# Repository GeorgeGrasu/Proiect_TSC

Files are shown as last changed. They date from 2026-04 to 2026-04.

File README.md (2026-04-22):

# InkTime ⌚ — Smartwatch Open Source

<p align="center">
  InkTime Smartwatch Render
</p>

**InkTime** este un smartwatch open-source, cu cost redus, construit în jurul **Nordic nRF52840** System-on-Chip, echipat cu un **display e-paper de 1.54"**. Proiectat pentru producție de masă, acest proiect acoperă designul hardware complet, de la schemă până la fișierele necesare fabricației.

---

## 📋 Cuprins
- [Diagrama Bloc](#diagrama-bloc)
- [Bill of Materials (BOM)](#bill-of-materials-bom)
- [Funcționalitatea Hardware](#funcționalitatea-hardware)
- [Maparea Pinilor nRF52840](#maparea-pinilor-nrf52840)
- [Analiza Consumului de Energie](#analiza-consumului-de-energie)
- [Designul PCB](#designul-pcb)
- [Design Mecanic](#design-mecanic)
- [Decizii de Design și Observații](#decizii-de-design-și-observații)
- [Structura Repository-ului](#structura-repository-ului)
- [Licență](#licență)

---

## Diagrama Bloc

<p align="center">
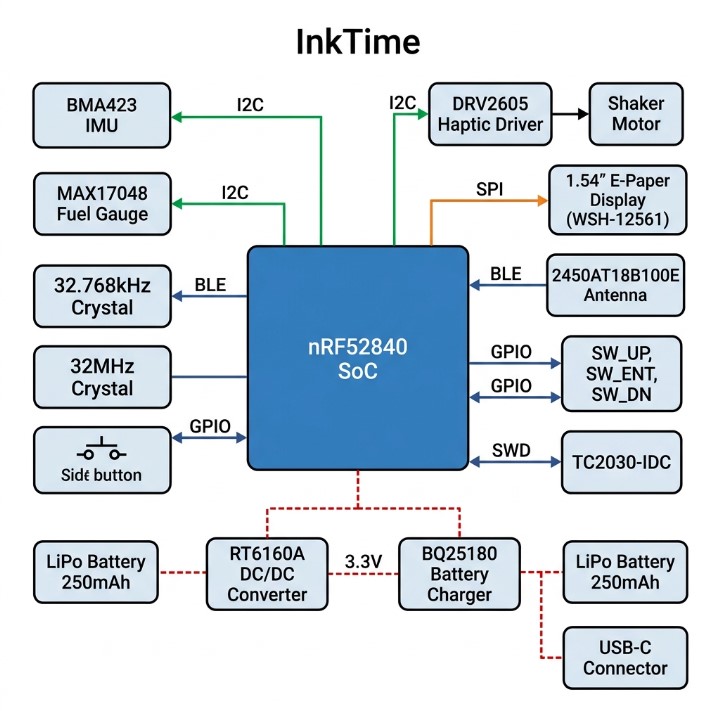
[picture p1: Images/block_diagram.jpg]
InkTime Diagrama Bloc
  
</p>

### Arhitectura Sistemului

```
                            ┌─────────────────────────────────────────────────┐
                            │              nRF52840 SoC (QFN48)              │
                            │                                                 │
                            │  ARM Cortex-M4F @ 64MHz                        │
                            │  1MB Flash / 256KB RAM                          │
                            │  Bluetooth 5.0 / BLE                            │
                            │  USB 2.0 Full Speed                             │
                            │                                                 │
  ┌──────────────┐   SPI    │  P0.02 (SCK)  ──┐                              │
  │  1.54" E-Ink │◄────────►│  P0.03 (MOSI) ──┤ SPI                          │
  │   Display    │          │  P0.28 (MISO) ──┤                              │
  │  (WSH-12561) │          │  P0.29 (CS)   ──┘                              │
  │  200x200 px  │          │  P0.04 (DC)                                     │
  │              │          │  P0.05 (RST)                                    │
  │              │          │  P0.06 (BUSY)                                   │
  └──────────────┘          │                                                 │
                            │                    ┌─────────────────────┐      │
  ┌──────────────┐   I2C    │  P0.26 (SDA) ─────►│ Magistrala I2C      │      │
  │  BMA423 IMU  │◄────────►│  P0.27 (SCL) ─────►│                     │      │
  │ Accelerometru│          │                    │  ├─ BMA423 (0x18)   │      │
  └──────────────┘          │                    │  ├─ MAX17048 (0x36) │      │
                            │                    │  └─ DRV2605 (0x5A)  │      │
  ┌──────────────┐   I2C    │                    └─────────────────────┘      │
  │  MAX17048    │◄─────────│                                                 │
  │ Fuel Gauge   │          │                                                 │
  └──────────────┘          │                                                 │
                            │                                                 │
  ┌──────────────┐   I2C    │                                                 │
  │  DRV2605     │◄─────────│                                                 │
  │ Driver Haptic│          │                                                 │
  │      │       │          │                                                 │
  │  ┌───▼────┐  │          │                                                 │
  │  │ Shaker │  │          │                                                 │
  │  │FIT0774 │  │          │                                                 │
  │  └────────┘  │          │                                                 │
  └──────────────┘          │                                                 │
                            │  P0.13 ──── SW_UP   (Buton)                     │
  ┌──────────────┐   GPIO   │  P0.14 ──── SW_ENT  (Buton)                     │
  │  3 Butoane   │◄────────►│  P0.15 ──── SW_DN   (Buton)                     │
  └──────────────┘          │                                                 │
                            │  P0.18 (D-) ──┐                                 │
  ┌──────────────┐   USB    │  P0.20 (D+) ──┤ USB 2.0 FS                     │
  │   USB-C      │◄────────►│               ──┘                              │
  │  Conector    │          │                                                 │
  │ (KH-TYPE-C)  │          │                                                 │
  └──────────────┘          │  SWDIO ──┐                                      │
                            │  SWDCLK ─┤ SWD Debug                           │
  ┌──────────────┐   SWD    │  SWO ────┘                                      │
  │   TC2030     │◄────────►│                                                 │
  │ Header Debug │          │                                                 │
  └──────────────┘          │  XC1/XC2 ─── Cristal 32 MHz                     │
                            │  P0.00/P0.01 ─── Cristal 32.768 kHz             │
  ┌──────────────┐          │                                                 │
  │  2450AT18B   │◄─────────│  ANT ──── Ieșire RF (2.4 GHz BLE)              │
  │ Antenă Chip  │          │                                                 │
  └──────────────┘          └─────────────────────────────────────────────────┘

  ┌─────────────────────────────────────────────────────────────────┐
  │                  SUBSISTEMUL DE ALIMENTARE                       │
  │                                                                 │
  │  ┌────────┐    ┌───────────┐    ┌───────────┐    ┌───────────┐ │
  │  │ USB-C  │───►│ BQ25180   │───►│ Baterie   │    │ RT6160A   │ │
  │  │  5V    │    │ Încărcător│    │ LiPo      │───►│ DC/DC     │ │
  │  │        │    │           │    │ 250mAh    │    │ Buck      │ │
  │  └────────┘    └───────────┘    │ 3.7V      │    │ 3.3V Ieș  │ │
  │                                 └───────────┘    └─────┬─────┘ │
  │  ┌────────────┐                                         │       │
  │  │ DMG2305UX  │◄── Comutator Sarcină (PMOS) ────────────┘       │
  │  │ P-MOSFET   │                                                 │
  │  └────────────┘         Linie 3.3V ──► Toate IC-urile           │
  └─────────────────────────────────────────────────────────────────┘
```

---

## Bill of Materials (BOM)

### Circuite Integrate și Module Principale

| # | Referință | Componentă | Valoare / Cod | Capsulă | Cant. | JLC Parts | Datasheet |
|---|---|---|---|---|-----|---|---|
| 1 | U1 | Microcontroler | nRF52840-QIAA | aQFN73 (7x7mm) | 1 | [C190794](https://jlcpcb.com/parts/componentSearch?isSearch=true&searchTxt=nRF52840) | [Datasheet](https://infocenter.nordicsemi.com/pdf/nRF52840_PS_v1.8.pdf) |
| 2 | IC2 | Încărcător Baterie | BQ25180YBGR | DSBGA-8 | 1 | [C2682092](https://jlcpcb.com/parts/componentSearch?isSearch=true&searchTxt=BQ25180) | [Datasheet](https://www.ti.com/lit/ds/symlink/bq25180.pdf) |
| 3 | IC9 | Convertor DC/DC | RT6160AWSC | WLCSP-15 | 1 | [C2828036](https://jlcpcb.com/parts/componentSearch?isSearch=true&searchTxt=RT6160A) | [Datasheet](https://www.richtek.com/assets/product_file/RT6160A/DS6160A-05.pdf) |
| 4 | U3 | Indicator Baterie | MAX17048G+T10 | DFN 2x2-8 | 1 | [C2682766](https://jlcpcb.com/parts/componentSearch?isSearch=true&searchTxt=MAX17048) | [Datasheet](https://datasheets.maximintegrated.com/en/ds/MAX17048-MAX17049.pdf) |
| 5 | IC3 | IMU / Accelerometru | BMA423 | LGA-12 | 1 | [C2831316](https://jlcpcb.com/parts/componentSearch?isSearch=true&searchTxt=BMA423) | [Datasheet](https://www.bosch-sensortec.com/products/motion-sensors/accelerometers/bma423/) |
| 6 | IC1 | Driver Haptic | DRV2605YZFR | BGA-9 | 1 | [C527680](https://jlcpcb.com/parts/componentSearch?isSearch=true&searchTxt=DRV2605) | [Datasheet](https://www.ti.com/lit/ds/symlink/drv2605.pdf) |
| 7 | D1 | Protecție ESD USB | USBLC6-2SC6Y | SOT-23-6 | 1 | [C7519](https://jlcpcb.com/parts/componentSearch?isSearch=true&searchTxt=USBLC6-2SC6Y) | [Datasheet](https://www.st.com/resource/en/datasheet/usblc6-2.pdf) |
| 8 | DMG2305UX | Comutator PMOS | DMG2305UX-7 | SOT-23-3 | 1 | [C150812](https://jlcpcb.com/parts/componentSearch?isSearch=true&searchTxt=DMG2305UX) | [Datasheet](https://www.diodes.com/assets/Datasheets/DMG2305UX.pdf) |
| 9 | Q3 | MOSFET (Driver motor) | SI1308EDL-T1-GE3 | SC-70-3 | 1 | [C515086](https://jlcpcb.com/parts/componentSearch?isSearch=true&searchTxt=SI1308EDL) | [Datasheet](https://www.vishay.com/docs/68743/si1308edl.pdf) |

### Conectori

| # | Referință | Componentă | Cod Componentă | Capsulă | Cant. | JLC Parts |
|---|---|---|---|---|-----|---|
| 10 | J1 | Conector FPC pentru EPD | 503480-2400 (24-pin, 0.5mm) | SMD | 1 | [C585393](https://jlcpcb.com/parts/componentSearch?isSearch=true&searchTxt=503480-2400) |
| 11 | J2 | Header de Debug | TC2030-IDC | Through-hole | 1 | [C5191042](https://jlcpcb.com/parts/componentSearch?isSearch=true&searchTxt=TC2030) |
| 12 | J4 | Conector USB-C | KH-TYPE-C-16P | SMD | 1 | [C2765186](https://jlcpcb.com/parts/componentSearch?isSearch=true&searchTxt=KH-TYPE-C-16P) |

### Componente Pasive

| # | Referință | Componentă | Valoare | Capsulă | Cant. |
|---|---|---|---|---|-----|
| 13 | C1, C2, C17, C18 | Condensator | 12pF | 0201 | 4 |
| 14 | C3, C4 | Condensator | 1pF | 0201 | 2 |
| 15 | C5, C7, C8, C12, C19 | Condensator | 100nF | 0201 | 5 |
| 16 | C6, C14, C20, C21 | Condensator | 4.7µF | 0402 | 4 |
| 17 | C9 | Condensator | 820pF | 0201 | 1 |
| 18 | C11 | Condensator | 100pF | 0201 | 1 |
| 19 | C16 | Condensator | 27nF | 0201 | 1 |
| 20 | C1-EP-DR | Condensator | 10µF | 0402 | 1 |
| 21 | C2-EP-DR | Condensator | 4.7µF/25V | 0402 | 1 |
| 22 | C23, C34 | Condensator | 0.1µF | 0201 | 2 |
| 23 | C24 | Condensator | 10µF | 0402 | 1 |
| 24 | C25, C33 | Condensator | 22µF | 0402 | 2 |
| 25 | C32 | Condensator | 1µF | 0402 | 1 |
| 26 | C43 | Condensator | 4.7µF | 0402 | 1 |
| 27 | C27, C29, C30, C31, C42 | Condensator | GRM011R60J152KE01 (1.5nF) | 0201 | 5 |
| 28 | EPD_C1, EPD_C2 | Condensator | 1µF/50V | 0402 | 2 |
| 29 | EPD_C5–C12 | Condensator | 0.1µF/50V | 0201 | 8 |
| 30 | L1 | Bobină | 3.9nH | 0402 | 1 |
| 31 | L2 | Bobină | 10µH | 0402 | 1 |
| 32 | L3 | Bobină | 15nH | 0402 | 1 |
| 33 | L5 | Bobină | 68µH | 4828 | 1 |
| 34 | L7 | Bobină | 0.47µH | 2016 | 1 |
| 35 | R17, R18, R1_EP_DR–R9, R_PWR_EPD, R_TYPE_SEL | Rezistoare | Diverse | 0402 | 14 |
| 36 | D3, D4, D5 | Diodă Schottky | MBR0530 | SOD-323 | 3 |
| 37 | ANT1 | Antenă Chip | 2450AT18B100E | 3216 | 1 |
| 38 | X1 | Cristal | 32 MHz | 2016 | 1 |
| 39 | X2 | Cristal | 32.768 kHz | 3215 | 1 |
| 40 | SW_UP, SW_ENT, SW_DN | Buton Tactil | EVP-AKE31A | SMD | 3 |
| 41 | SJ1 | Jumper de Lipit | – | SMD | 1 |
| 42 | TP_* | Pad-uri de Test | – | TP20R | 14 |

### Componente Externe (nu sunt pe PCB)

| # | Componentă | Cod | Specificații | Link |
|---|---|---|---|---|
| 43 | Baterie LiPo | Akyga AKY0106 (LP502030) | 3.7V, 250mAh, 30×20×5mm | [TME](https://www.tme.eu/Document/b9e12bf26ad0ba929a22ab5d58f022cd/AKY0106.pdf) |
| 44 | Display E-Paper | Waveshare WSH-12561 (1.54") | 200×200px, 31.8×37.32×1.05mm | [TME](https://www.tme.eu/Document/0ca57a8ffbcd57b5bca53252eb9d6ec3/WSH-12561.pdf) |
| 45 | Motor de Vibrație | DFRobot FIT0774 | Ø10×2.7mm, 3V/50mA | [DFRobot](https://www.tme.eu/ro/details/df-fit0774/motoare-dc/dfrobot/fit0774/) |

---

## Funcționalitatea Hardware

### 1. Procesor și Conectivitate — nRF52840 (U1)

**Nordic nRF52840** este SoC-ul principal, oferind:
- **ARM Cortex-M4F** la **64 MHz** cu FPU (unitate de calcul în virgulă mobilă)
- **1 MB Flash** și **256 KB RAM**
- **Bluetooth 5.0 / BLE** prin radio integrat la 2.4 GHz
- **USB 2.0 Full-Speed** pentru transfer de date și negociere de încărcare
- **Convertor DC/DC integrat** pentru management eficient al puterii
- **ARM TrustZone CryptoCell-310** pentru securitate

nRF52840 este în capsulă **QFN73 (7×7mm)** cu matrice de pad-uri de tip BGA, suficient de compact pentru aplicații wearable.

**Surse de ceas:**
- **X1**: Cristal de 32 MHz — ceasul principal de sistem pentru radio și CPU
- **X2**: Cristal de 32.768 kHz — RTC de consum redus și timer de sleep

### 2. Display E-Paper — WSH-12561 (prin J1)

**Display-ul Waveshare e-paper de 1.54"** oferă:
- Rezoluție de **200×200 pixeli**
- **Consum ultra-redus** — consumă energie doar la reîmprospătare (refresh)
- **Interfață SPI** pentru comunicare rapidă
- Conectat prin conector **FPC cu 24 de pini, pas 0.5mm** (J1: Molex 503480-2400)

Circuitul driver EPD al display-ului necesită mai multe tensiuni de alimentare, generate prin pompele de sarcină (charge pumps) cu condensatoarele EPD_C1–C12.

**Semnale de interfață:**
| Semnal | Pin nRF52840 | Descriere |
|---|---|---|
| SCLK | P0.02 | Ceas SPI |
| MOSI | P0.03 | Date SPI spre display |
| MISO | P0.28 | Date SPI de la display |
| CS | P0.29 | Chip Select (activ pe low) |
| DC | P0.04 | Selectare Date/Comandă |
| RST | P0.05 | Reset display (activ pe low) |
| BUSY | P0.06 | Indicator display ocupat |

### 3. Unitate de Măsură Inerțială — BMA423 (IC3)

**Bosch BMA423** este un accelerometru digital pe 3 axe, oferind:
- Numărare pași, recunoaștere activitate, detecție gesturi
- **Interfață I2C** (adresă: 0x18)
- Consum ultra-redus (~14 µA în modul low-power)
- Ideal pentru detecția ridicării încheieturii (wake on raise)

Conectat prin magistrala I2C comună (SDA: P0.26, SCL: P0.27).

### 4. Managementul Bateriei — BQ25180 (IC2) + MAX17048 (U3)

**Încărcător Baterie BQ25180 (IC2):**
- **Încărcător liniar** optimizat pentru dispozitive wearable
- Intrare de la USB-C (VBUS, 5V)
- Curent de încărcare programabil
- Parametri de încărcare **configurabili prin I2C**
- Capsulă compactă **DSBGA-8** (1.0×1.55mm)

**Indicator Baterie MAX17048 (U3):**
- Algoritm **ModelGauge™** — nu necesită rezistor de sens
- Raportează **starea de încărcare (SOC %)** și tensiunea
- **Interfață I2C** (adresă: 0x36)
- Curent de repaus ultra-redus (~23 µA)
- Capsulă **DFN 2×2mm**

**Traseul de alimentare:**
USB-C 5V → BQ25180 → Baterie LiPo (3.7V) → RT6160A → Linie de 3.3V pentru sistem

### 5. Regulare de Tensiune — RT6160A (IC9)

**Richtek RT6160A** este un convertor DC/DC de tip buck:
- Intrare: 2.5V – 5.5V (de la baterie sau USB)
- Ieșire: **3.3V** reglat
- Curent de ieșire de până la **2A**
- **Eficiență de 96%** la sarcină tipică
- Capsulă **WLCSP-15** (1.4×2.3mm)

Linia de 3.3V alimentează toate circuitele integrate, senzorii și display-ul.

**Componente suport:**
- **L7** (0.47µH) — bobina principală de comutare
- **C25, C33** (22µF) — condensatoare de ieșire
- **C23** (0.1µF), **C24** (10µF) — condensatoare de intrare

### 6. Feedback Haptic — DRV2605 (IC1) + FIT0774

**TI DRV2605** — driver pentru feedback haptic:
- Suport integrat pentru motoare **ERM și LRA**
- **Bibliotecă de 123 efecte haptice** (forme de undă)
- **Interfață I2C** (adresă: 0x5A)
- Conectat la motorul de vibrație **DFRobot FIT0774** (Ø10×2.7mm)
- Moduri de intrare PWM și analogic disponibile

### 7. Interfața USB-C — KH-TYPE-C-16P (J4)

- Conector **USB Type-C cu 16 pini**
- Suportă **USB 2.0 Full Speed** (D+/D- prin nRF52840)
- **Protecție ESD** prin USBLC6-2SC6Y (D1)
- **Rezistoarele pull-down CC** (R1_USB, R2_USB) pentru detectarea corectă USB-C
- Furnizează de asemenea **alimentare VBUS** către încărcătorul BQ25180

### 8. Interfața Utilizator — 3 Butoane

Trei butoane tactile **EVP-AKE31A** pentru navigare:
| Buton | Pin nRF52840 | Funcție |
|---|---|---|
| SW_UP | P0.13 | Derulare sus / Anterior |
| SW_ENT | P0.14 | Selectare / Enter |
| SW_DN | P0.15 | Derulare jos / Următor |

Amplasate pe marginea stângă a PCB-ului pentru operare ca butoane laterale. Fiecare buton este conectat cu pull-up intern și utilizează detecție de întrerupere pe front descrescător.

### 9. Interfața de Debug — TC2030-IDC (J2)

**Tag-Connect TC2030-IDC** oferă:
- Interfață **SWD (Serial Wire Debug)**
- Footprint cu **pini pogo fără picioare** (economisește spațiu pe PCB)
- Semnale: SWDIO, SWDCLK, SWO, VCC, GND, RESET

### 10. Antena BLE — 2450AT18B100E (ANT1)

- Antenă chip **Johanson 2450AT18B100E**
- **2.4 GHz** pentru Bluetooth Low Energy
- Footprint **3.2×1.6mm** (capsulă 3216)
- Rețea de adaptare: L1 (3.9nH), C3, C4 (1pF)
- **Amplasare critică**: la marginea plăcii, cu decupaj în planul de masă sub antenă

### 11. Protecție și Comutare de Putere

- **DMG2305UX-7** MOSFET canal P — comutator de sarcină pentru managementul puterii
- **MBR0530** diode Schottky (D3, D4, D5) — protecție la tensiune inversă pe liniile de alimentare
- **SI1308EDL** MOSFET canal N (Q3) — comutare motor/periferice

---

## Maparea Pinilor nRF52840

| Pin | GPIO | Funcție | Interfață | Direcție | Note |
|-----|---|---|---|---|---|
| P0.00 | XL1 | Cristal 32.768 kHz | LFCLK | I/O | Ceas de frecvență joasă |
| P0.01 | XL2 | Cristal 32.768 kHz | LFCLK | I/O | Ceas de frecvență joasă |
| P0.02 | AIN0 | Ceas SPI EPD | SPI SCK | Ieșire | Ceas display e-paper |
| P0.03 | AIN1 | SPI MOSI EPD | SPI MOSI | Ieșire | Date spre display |
| P0.04 | AIN2 | Date/Comandă EPD | GPIO | Ieșire | Selectare D/C |
| P0.05 | AIN3 | Reset EPD | GPIO | Ieșire | Reset activ pe low |
| P0.06 | AIN4 | Busy EPD | GPIO | Intrare | Indicator display ocupat |
| P0.13 | — | Buton SUS | GPIO | Intrare | Pull-up intern, IRQ |
| P0.14 | — | Buton ENTER | GPIO | Intrare | Pull-up intern, IRQ |
| P0.15 | — | Buton JOS | GPIO | Intrare | Pull-up intern, IRQ |
| P0.18 | — | USB D- | USB | I/O | Date USB 2.0 minus |
| P0.20 | — | USB D+ | USB | I/O | Date USB 2.0 plus |
| P0.26 | — | I2C SDA | TWI | I/O | Date I2C partajate |
| P0.27 | — | I2C SCL | TWI | Ieșire | Ceas I2C partajat |
| P0.28 | AIN4 | SPI MISO EPD | SPI MISO | Intrare | Date de la display |
| P0.29 | AIN5 | SPI CS EPD | SPI CS | Ieșire | Selectare chip, activ low |
| SWDIO | — | Date Debug | SWD | I/O | Programare/depanare |
| SWDCLK | — | Ceas Debug | SWD | Intrare | Programare/depanare |
| SWO | — | Trasare Debug | SWD | Ieșire | Ieșire de trasare |
| XC1 | — | Cristal 32 MHz | HFCLK | I/O | Ceas de frecvență înaltă |
| XC2 | — | Cristal 32 MHz | HFCLK | I/O | Ceas de frecvență înaltă |
| ANT | — | Antenă RF | Radio | Ieșire | Antenă BLE 2.4 GHz |
| VDD | — | Alimentare | PWR | Intrare | 3.3V de la RT6160A |
| VSS | — | Masă | PWR | — | Planul de masă |
| DEC1–DEC6 | — | Decuplare | PWR | — | Condensatoare 100nF necesare |

**Motivarea alegerii pinilor:**
- **P0.02–P0.06** au fost aleși pentru display-ul SPI deoarece suportă perifericul SPIM la viteză mare și sunt adiacenți pentru rutare curată
- **P0.13–P0.15** pentru butoane deoarece aceste GPIO-uri suportă GPIOTE (evenimente/întreruperi) și nu au conflicte cu funcții alternative
- **P0.26–P0.27** pentru I2C deoarece aceștia sunt pinii impliciți TWI0 ai nRF52840
- **P0.18, P0.20** sunt pinii dedicați USB D-/D+ (nu există alternativă)
- **P0.28–P0.29** pentru semnale SPI suplimentare, utilizând pinii AIN care sunt liberi deoarece nu folosim ADC-ul în acest design

---

## Analiza Consumului de Energie

### Bugetul de Putere per Componentă

| Componentă | Curent Activ | Curent Sleep/Idle | Ciclu de Lucru | Curent Mediu |
|---|---|---|---|---|
| nRF52840 (CPU activ) | 3.2 mA | 1.5 µA (System OFF) | 5% | 161.5 µA |
| nRF52840 (BLE TX) | 4.8 mA | — | 1% | 48 µA |
| Display E-Paper | 15 mA (refresh) | 0 µA (static) | 0.5% | 75 µA |
| BMA423 IMU | 150 µA | 14 µA (low-power) | 10% | 27.6 µA |
| MAX17048 Fuel Gauge | 23 µA | 23 µA (mereu activ) | 100% | 23 µA |
| DRV2605 + Motor | 50 mA | 0.25 µA (standby) | 0.1% | 50.3 µA |
| RT6160A Quiescent | — | 25 µA | 100% | 25 µA |
| **TOTAL** | — | — | — | **~410 µA** |

### Estimarea Autonomiei Bateriei

| Parametru | Valoare |
|---|---|
| Capacitate baterie | 250 mAh |
| Curent mediu de sistem | ~410 µA |
| **Autonomie estimată** | **~610 ore (~25 zile)** |
| Cu optimizare agresivă de sleep | **~40+ zile** |

> **Notă:** Display-ul e-paper are consum zero de energie atunci când afișează o imagine statică, ceea ce este ideal pentru o aplicație de ceas. Display-ul consumă energie doar în timpul reîmprospătării (~2 secunde per actualizare). Advertising-ul BLE la intervale de 1 secundă adaugă ~48 µA în medie.

---

## Designul PCB

### Specificații Placă

| Parametru | Valoare |
|---|---|
| Straturi | 2 (Top + Bottom) |
| Material | FR-4 |
| Grosime | 1.6 mm |
| Greutate cupru | 1 oz (35 µm) |
| Finisaj suprafață | HASL/ENIG |
| Lățime minimă traseu | 0.15 mm (semnale), 0.3 mm (putere) |
| Dimensiune minimă via | 0.3 mm gaură / 0.6 mm pad |
| Față cu componente | Doar TOP |

### Reguli de Design Aplicate

- ✅ **Trasee de putere**: lățime 0.3 mm (mai înguste sub BGA unde este necesar)
- ✅ **Trasee de semnal**: ≥0.15 mm lățime
- ✅ **Fără unghiuri drepte** în rutarea traseelor (45° sau curbate)
- ✅ **Condensatoare de decuplare** (100nF) plasate cât mai aproape de pinii de alimentare ai IC-urilor
- ✅ **Planuri de masă** atât pe TOP cât și pe BOTTOM
- ✅ **Via stitching** între planurile de masă (în special lângă secțiunea RF)
- ✅ **Zona antenei**: planul de masă eliminat sub antenă, fără rutare de semnale pe sub antenă
- ✅ **DRC verificat** folosind regulile de design JLCPCB 2 straturi
- ✅ **Componente plasate exclusiv pe layer-ul TOP**
- ✅ **Pad-urile de test clar marcate** în silkscreen cu numele semnalelor

### Randări PCB

<p align="center">
  PCB Vedere 3D
  <br><em>PCB — Randare 3D</em>
</p>

---

## Design Mecanic

### Dimensiuni Componente

| Componentă | Lungime (mm) | Lățime (mm) | Înălțime (mm) | Sursă |
|---|---|---|---|---|
| Baterie (AKY0106) | 30.0 | 20.0 | 5.0 | [Datasheet](https://www.tme.eu/Document/b9e12bf26ad0ba929a22ab5d58f022cd/AKY0106.pdf) |
| Display (WSH-12561) | 37.32 | 31.80 | 1.05 | [Datasheet](https://www.tme.eu/Document/0ca57a8ffbcd57b5bca53252eb9d6ec3/WSH-12561.pdf) |
| Shaker (FIT0774) | Ø10.0 | Ø10.0 | 2.7 | [DFRobot](https://www.dfrobot.com/product-2288.html) |
| PCB | ~40 | ~36 | 1.6 | Design propriu |
| Carcasă (exterior) | ~42 | ~38 | ~12 | inktime_case.f3z |

### Stack-up Asamblare (de jos în sus)

```
┌─────────────────────────┐
│   Capac Carcasă / Sticlă │  ~1.7 mm
├─────────────────────────┤
│    Display E-Paper       │  1.05 mm
├─────────────────────────┤
│    PCB (cu IC-uri)       │  1.6 mm + ~1 mm (componente)
├─────────────────────────┤
│  Baterie + Shaker        │  5.0 mm (baterie) / 2.7 mm (shaker)
├─────────────────────────┤
│   Baza Carcasei          │  ~1.0 mm perete
└─────────────────────────┘
```

### Modele 3D

Modele parametrice OpenSCAD sunt furnizate în folderul `Mechanical/`:
- `battery_AKY0106.scad` — Model baterie cu dimensiuni exacte
- `display_WSH12561.scad` — Display e-paper cu cablu FPC
- `shaker_FIT0774.scad` — Motor de vibrație tip monedă
- `full_assembly.scad` — Ansamblu complet cu opțiune de vedere explodată

> **Pentru export ca STEP:** Deschideți în OpenSCAD → Exportați ca STL → Importați în FreeCAD/Fusion 360 → Exportați ca STEP

### Vedere Explodată

<p align="center">
  Vedere Explodată Ansamblu
  <br><em>Vedere explodată a ansamblului smartwatch-ului InkTime</em>
</p>

<p align="center">
  Smartwatch fără ecran
  <br><em>Smartwatch-ul InkTime fără ecran (vedere interioară)</em>
</p>

---

## Decizii de Design și Observații

### Decizii Cheie de Design

1. **Conectarea bateriei prin pad-uri de test (fără conector JST)**
   - Decizie: Firele bateriei sunt lipite direct pe pad-urile de test TP_BAT și TP_BAT_GND
   - Motiv: Economisire de spațiu pe înălțime (Z) în interiorul carcasei; conectorul JST ar adăuga ~3mm înălțime

2. **PCB cu 2 straturi**
   - Planuri de masă atât pe TOP cât și pe BOTTOM
   - Via stitching folosit extensiv lângă secțiunea RF/antenă pentru continuitatea masei
   - Majoritatea rutării pe layer-ul TOP; BOTTOM folosit pentru masa și câteva trasee de semnal

3. **Toate componentele pe layer-ul TOP**
   - Conform cerințelor proiectului, toate componentele SMD sunt plasate exclusiv pe TOP
   - Aceasta simplifică asamblarea (reflow pe o singură față) și reduce costul

4. **Componente pasive**
   - Toate rezistoarele sunt SMD 0402
   - Condensatoarele ≤100nF sunt 0201, >100nF sunt 0402
   - Excepție: valori mai mari (22µF) și capsule specifice notate în schemă

5. **Amplasarea antenei**
   - Antena chip (2450AT18B100E) plasată la marginea plăcii
   - Cuprul de masă al PCB-ului eliminat sub footprint-ul antenei
   - Fără rutare de semnale sub sau în apropierea zonei antenei
   - Rețea de adaptare (L1=3.9nH, C3/C4=1pF) acordată conform designului de referință Nordic

### Note ERC/DRC Acceptate

- ⚠️ **"Only INPUT pins on NET ID"** — Această eroare ERC este așteptată și poate fi ignorată în siguranță conform ghidului proiectului
- ⚠️ **Erori de dimensiune de la butoane/USB** — Cele trei butoane tactile și conectorul USB-C se extind ușor dincolo de conturul PCB-ului pentru acces mecanic din carcasă. Aceste încălcări de dimensiune sunt intenționate și acceptate
- ⚠️ **Variația lățimii traseelor sub BGA** — Sub capsula QFN a nRF52840, lățimile traseelor sunt reduse pentru a încăpea între pad-uri. Traseele de putere revin la lățimea de 0.3mm după ieșirea din zona BGA

### Jurnal de Design

| Săptămâna | Activitate |
|---|---|
| Săpt. 1 | Studiu documente InkTime MRD/PRD/ERD, analiză design de referință nRF52840 |
| Săpt. 2 | Implementare schemă în Fusion 360 Electronics folosind biblioteca furnizată |
| Săpt. 3 | Layout PCB — amplasare componente respectând constrângerile mecanice |
| Săpt. 4 | Rutare trasee, verificare DRC, planuri de masă, via stitching |
| Săpt. 5 | Generare Gerber, export BOM/PnP, modelare 3D, documentație |

---

## Structura Repository-ului

```
proiect_TSC/
├── Hardware/
│   ├── SchematicBomba.sch          # Fișier schemă Fusion 360
│   └── PCB.brd                     # Fișier layout placă Fusion 360
├── Manufacturing/
│   ├── GerberFiles.zip             # Fișiere Gerber pentru fabricația PCB
│   ├── Assembly/
│   │   ├── PCB.txt                 # Bill of Materials (BOM)
│   │   └── PnP_PCB_front.txt      # Fișier Pick and Place (CPL)
│   └── DrillFiles/
│       └── drill_1_64.xln          # Fișier de găurire Excellon
├── Mechanical/
│   ├── battery_AKY0106.scad        # Model 3D — Baterie LiPo (30×20×5mm)
│   ├── display_WSH12561.scad       # Model 3D — Display e-paper 1.54"
│   ├── shaker_FIT0774.scad         # Model 3D — Motor vibrație (Ø10×2.7mm)
│   └── full_assembly.scad          # Ansamblu complet cu vedere explodată
├── Images/
│   ├── 3dpcb.jpg                   # Randare PCB 3D
│   ├── block_diagram.jpg           # Diagrama bloc a sistemului
│   ├── inktime-3d-expanded-view.jpg# Vedere explodată ansamblu
│   ├── inktime-full-watch.jpg      # Randare ceas complet
│   └── inktime-watch-no-screen.jpg # Randare ceas fără ecran
├── LICENSE                         # Licență Apache 2.0
└── README.md                       # Acest fișier
```

---

## Licență

Acest proiect este licențiat sub **Apache License 2.0** — vezi fișierul [LICENSE](LICENSE) pentru detalii.

```
Copyright 2026 Proiect InkTime

Licensed under the Apache License, Version 2.0
```

---

<p align="center">
  <b>InkTime</b> — Proiect Smartwatch Open Source<br>
  TSC • Universitatea Politehnica din București
</p>

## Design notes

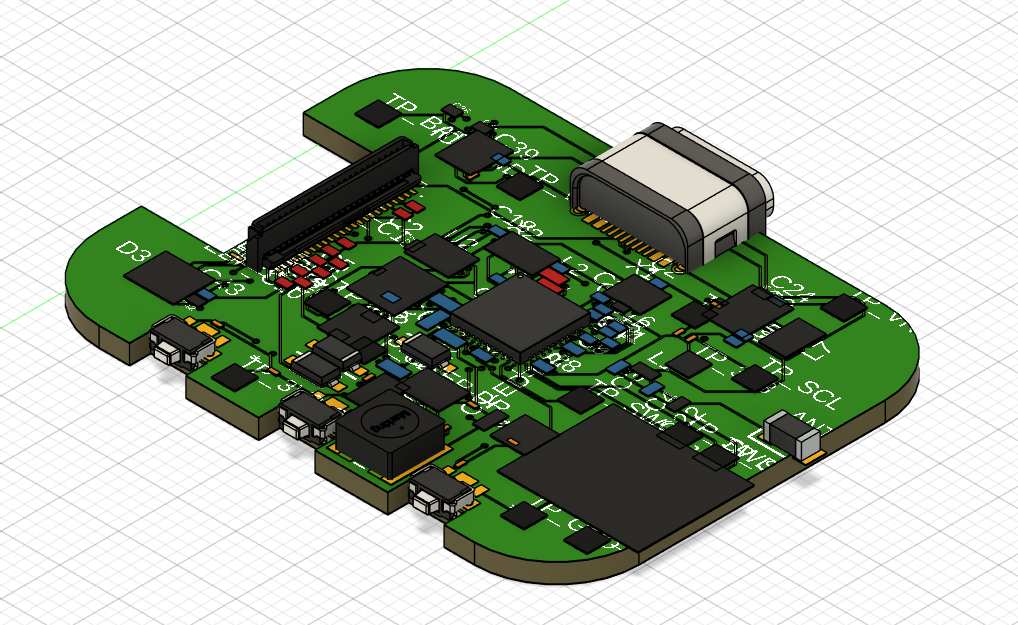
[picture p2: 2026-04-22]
Images/Capture6.PNG

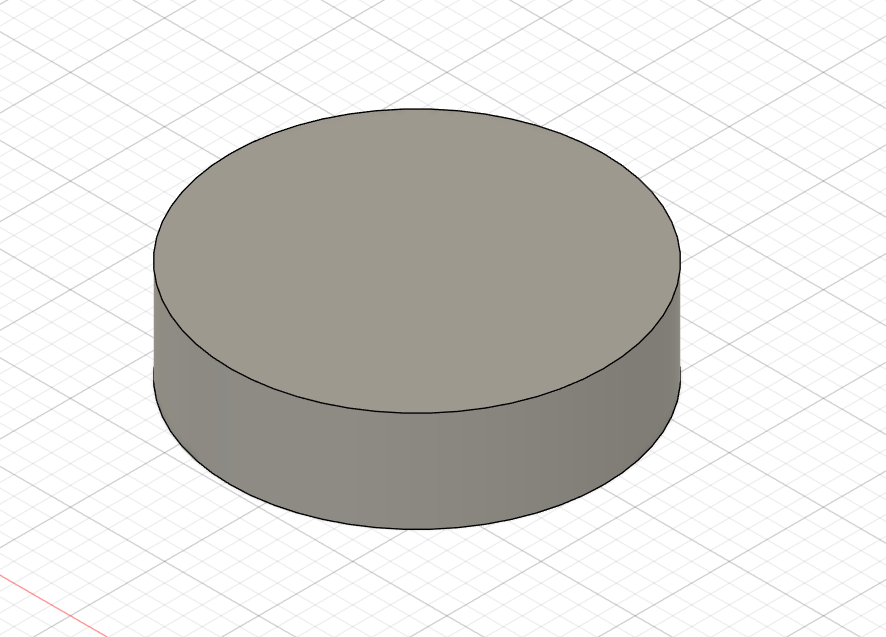
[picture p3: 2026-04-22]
Images/Capture4.PNG

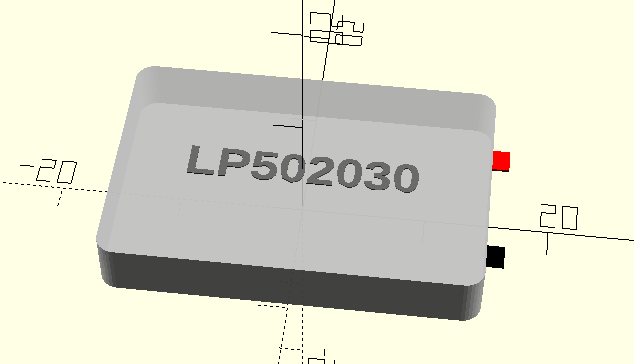
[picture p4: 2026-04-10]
Images/capture5 (2).PNG

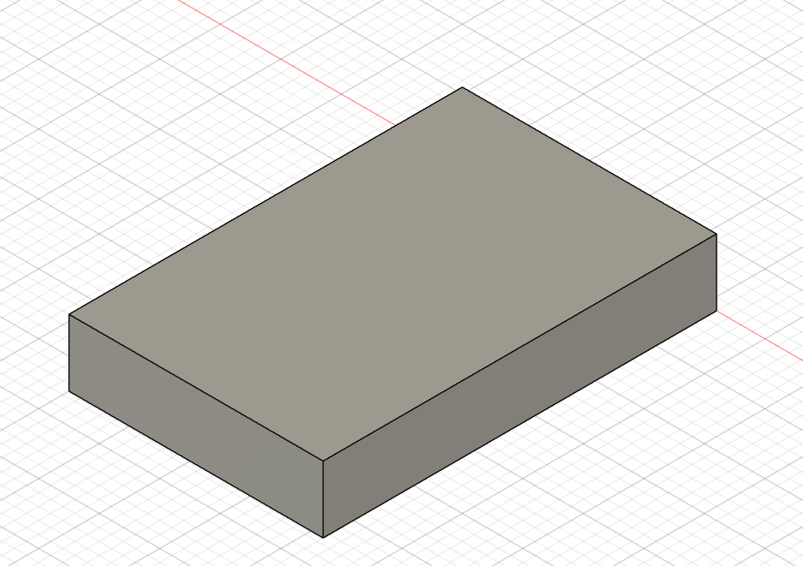
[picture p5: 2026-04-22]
Images/Capture3.PNG

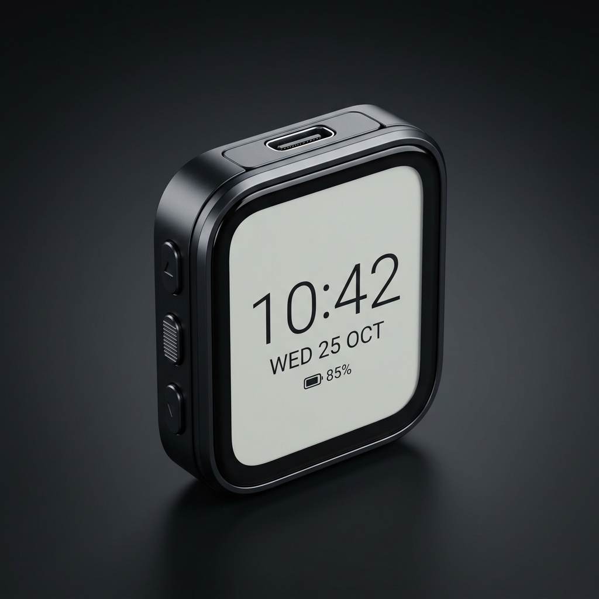
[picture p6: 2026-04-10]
Images/watch_render.png

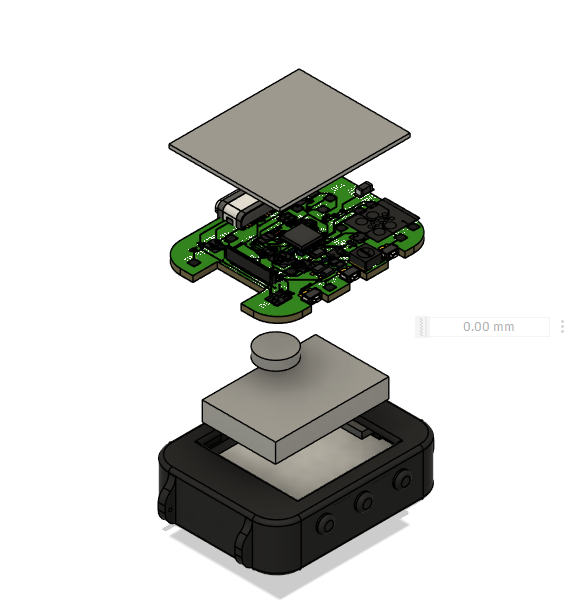
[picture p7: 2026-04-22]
Images/Capture5.PNG

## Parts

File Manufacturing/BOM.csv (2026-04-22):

Part | Value | Device | Footprint Name | Detailed Description | ARROW_PART_NUMBER | ARROW_PRICE-STOCK | AVAILABILITY | CHECK_PRICES | COPYRIGHT | DESCRIPTION | DIGI-KEY_PART_NUMBER_1 | DIGI-KEY_PART_NUMBER_2 | DIGI-KEY_PART_NUMBER_3 | HEIGHT | JLCPCB | MANUFACTURER_NAME | MANUFACTURER_PART_NUMBER | MF | MFR_NAME | MOUSER_PART_NUMBER | MOUSER_PRICE-STOCK | MP | PACKAGE | POPULARITY | PRICE | PROD_ID | PURCHASE-URL | SNAPEDA_LINK | TP_SIGNAL_NAME | VALUE
ANT1 | 2450AT18B100E | 2450AT18B100E_2450AT18B100E | 2450AT18B100E_ANTC3216X140N | Antennas 2.45GHz ANTENNA | 2450AT18B100E | https://www.arrow.com/en/products/2450at18b100e/johanson-dielectrics?utm_currency=USD&region=nac |  |  |  | Antennas 2.45GHz ANTENNA |  |  |  | 1.4mm |  | JOHANSON TECHNOLOGY | 2450AT18B100E |  |  | 609-2450AT18B100E | https://www.mouser.co.uk/ProductDetail/Johanson-Technology/2450AT18B100E?qs=yCnrNFeXz%252Bh5MFsFIXGZGA%3D%3D
C1 | 12pF | NORDIC_NRF_3_CAPACITOR_0201_L | NORDIC_NRF_3_RESC0201_L | Generic chip capacitor
C1-ED-DR | 10uF | NORDIC_NRF_3_CAPACITOR_0402_N | NORDIC_NRF_3_RESC0402_N | Generic chip capacitor
C2 | 12pF | NORDIC_NRF_3_CAPACITOR_0201_L | NORDIC_NRF_3_RESC0201_L | Generic chip capacitor
C2-EP-DR | 4.7uF | NORDIC_NRF_3_CAPACITOR_0402_N | NORDIC_NRF_3_RESC0402_N | Generic chip capacitor
C3 | 1pF | NORDIC_NRF_3_CAPACITOR_0201_N | NORDIC_NRF_3_RESC0201_N | Generic chip capacitor
C4 | 1pF | NORDIC_NRF_3_CAPACITOR_0201_N | NORDIC_NRF_3_RESC0201_N | Generic chip capacitor
C5 | 100nF | NORDIC_NRF_3_CAPACITOR_0201_L | NORDIC_NRF_3_RESC0201_L | Generic chip capacitor
C6 | 4.7uF | NORDIC_NRF_3_CAPACITOR_0402_N | NORDIC_NRF_3_RESC0402_N | Generic chip capacitor
C7 | 100nF | NORDIC_NRF_3_CAPACITOR_0201_N | NORDIC_NRF_3_RESC0201_N | Generic chip capacitor
C8 | 100nF | NORDIC_NRF_3_CAPACITOR_0201_N | NORDIC_NRF_3_RESC0201_N | Generic chip capacitor
C9 | 820pF | NORDIC_NRF_3_CAPACITOR_0201_N | NORDIC_NRF_3_RESC0201_N | Generic chip capacitor
C10 | N.C. | NORDIC_NRF_3_CAPACITOR_0201_L | NORDIC_NRF_3_RESC0201_L | Generic chip capacitor
C11 | 100pF | NORDIC_NRF_3_CAPACITOR_0201_L | NORDIC_NRF_3_RESC0201_L | Generic chip capacitor
C12 | 100nF | NORDIC_NRF_3_CAPACITOR_0201_L | NORDIC_NRF_3_RESC0201_L | Generic chip capacitor
C13 | N.C. | NORDIC_NRF_3_CAPACITOR_0201_L | NORDIC_NRF_3_RESC0201_L | Generic chip capacitor
C14 | 4.7uF | NORDIC_NRF_3_CAPACITOR_0201_L | NORDIC_NRF_3_RESC0201_L | Generic chip capacitor
C15 | 1.0uF | NORDIC_NRF_3_CAPACITOR_0201_L | NORDIC_NRF_3_RESC0201_L | Generic chip capacitor
C16 | 47nF | NORDIC_NRF_3_CAPACITOR_0201_L | NORDIC_NRF_3_RESC0201_L | Generic chip capacitor
C17 | 12pF | NORDIC_NRF_3_CAPACITOR_0201_L | NORDIC_NRF_3_RESC0201_L | Generic chip capacitor
C18\ | 12pF | NORDIC_NRF_3_CAPACITOR_0201_L | NORDIC_NRF_3_RESC0201_L | Generic chip capacitor
C19 | 100nF | NORDIC_NRF_3_CAPACITOR_0201_L | NORDIC_NRF_3_RESC0201_L | Generic chip capacitor
C20 | 4.7uF | NORDIC_NRF_3_CAPACITOR_0402_N | NORDIC_NRF_3_RESC0402_N | Generic chip capacitor
C21 | 4.7uF | NORDIC_NRF_3_CAPACITOR_0402_N | NORDIC_NRF_3_RESC0402_N | Generic chip capacitor
C22 | N.C. | NORDIC_NRF_3_CAPACITOR_0201_N | NORDIC_NRF_3_RESC0201_N | Generic chip capacitor
C23 | 0.1uF | GRM011R60J152KE01L_2_GRM011R60J152KE01L | GRM011R60J152KE01L_2_CAPC0201X13N | Check availability |  |  | In Stock | https://www.snapeda.com/parts/GRM011R60J152KE01L/Murata/view-part/?ref=eda |  | SMD Capacitor X5R(EIA) with Capacitance: 1500pF Tol. 10%. Rated Voltage: 6.3Vdc |  |  |  |  |  |  |  | Murata |  |  |  | GRM011R60J152KE01L | 0201 Murata |  | None |  |  | https://www.snapeda.com/parts/GRM011R60J152KE01L/Murata/view-part/?ref=snap
C24 | 10uF | NORDIC_NRF_3_CAPACITOR_0201_L | NORDIC_NRF_3_RESC0201_L | Generic chip capacitor
C25 | 22uF | NORDIC_NRF_3_CAPACITOR_0201_L | NORDIC_NRF_3_RESC0201_L | Generic chip capacitor
C27 | 0.1uF | GRM011R60J152KE01L_2_GRM011R60J152KE01L | GRM011R60J152KE01L_2_CAPC0201X13N | Check availability |  |  | In Stock | https://www.snapeda.com/parts/GRM011R60J152KE01L/Murata/view-part/?ref=eda |  | SMD Capacitor X5R(EIA) with Capacitance: 1500pF Tol. 10%. Rated Voltage: 6.3Vdc |  |  |  |  |  |  |  | Murata |  |  |  | GRM011R60J152KE01L | 0201 Murata |  | None |  |  | https://www.snapeda.com/parts/GRM011R60J152KE01L/Murata/view-part/?ref=snap
C29 | 1uF | GRM011R60J152KE01L_2_GRM011R60J152KE01L | GRM011R60J152KE01L_2_CAPC0201X13N | Check availability |  |  | In Stock | https://www.snapeda.com/parts/GRM011R60J152KE01L/Murata/view-part/?ref=eda |  | SMD Capacitor X5R(EIA) with Capacitance: 1500pF Tol. 10%. Rated Voltage: 6.3Vdc |  |  |  |  |  |  |  | Murata |  |  |  | GRM011R60J152KE01L | 0201 Murata |  | None |  |  | https://www.snapeda.com/parts/GRM011R60J152KE01L/Murata/view-part/?ref=snap
C30 | 1uF | GRM011R60J152KE01L_2_GRM011R60J152KE01L | GRM011R60J152KE01L_2_CAPC0201X13N | Check availability |  |  | In Stock | https://www.snapeda.com/parts/GRM011R60J152KE01L/Murata/view-part/?ref=eda |  | SMD Capacitor X5R(EIA) with Capacitance: 1500pF Tol. 10%. Rated Voltage: 6.3Vdc |  |  |  |  |  |  |  | Murata |  |  |  | GRM011R60J152KE01L | 0201 Murata |  | None |  |  | https://www.snapeda.com/parts/GRM011R60J152KE01L/Murata/view-part/?ref=snap
C31 | 1uF | GRM011R60J152KE01L_2_GRM011R60J152KE01L | GRM011R60J152KE01L_2_CAPC0201X13N | Check availability |  |  | In Stock | https://www.snapeda.com/parts/GRM011R60J152KE01L/Murata/view-part/?ref=eda |  | SMD Capacitor X5R(EIA) with Capacitance: 1500pF Tol. 10%. Rated Voltage: 6.3Vdc |  |  |  |  |  |  |  | Murata |  |  |  | GRM011R60J152KE01L | 0201 Murata |  | None |  |  | https://www.snapeda.com/parts/GRM011R60J152KE01L/Murata/view-part/?ref=snap
C32 | 1uF | GRM011R60J152KE01L_2_GRM011R60J152KE01L | GRM011R60J152KE01L_2_CAPC0201X13N | Check availability |  |  | In Stock | https://www.snapeda.com/parts/GRM011R60J152KE01L/Murata/view-part/?ref=eda |  | SMD Capacitor X5R(EIA) with Capacitance: 1500pF Tol. 10%. Rated Voltage: 6.3Vdc |  |  |  |  |  |  |  | Murata |  |  |  | GRM011R60J152KE01L | 0201 Murata |  | None |  |  | https://www.snapeda.com/parts/GRM011R60J152KE01L/Murata/view-part/?ref=snap
C33 | 22uF | NORDIC_NRF_3_CAPACITOR_0201_L | NORDIC_NRF_3_RESC0201_L | Generic chip capacitor
C34 | 0.1uF | GRM011R60J152KE01L_2_GRM011R60J152KE01L | GRM011R60J152KE01L_2_CAPC0201X13N | Check availability |  |  | In Stock | https://www.snapeda.com/parts/GRM011R60J152KE01L/Murata/view-part/?ref=eda |  | SMD Capacitor X5R(EIA) with Capacitance: 1500pF Tol. 10%. Rated Voltage: 6.3Vdc |  |  |  |  |  |  |  | Murata |  |  |  | GRM011R60J152KE01L | 0201 Murata |  | None |  |  | https://www.snapeda.com/parts/GRM011R60J152KE01L/Murata/view-part/?ref=snap
C37 | 1uF | GRM011R60J152KE01L_2_GRM011R60J152KE01L | GRM011R60J152KE01L_2_CAPC0201X13N | Check availability |  |  | In Stock | https://www.snapeda.com/parts/GRM011R60J152KE01L/Murata/view-part/?ref=eda |  | SMD Capacitor X5R(EIA) with Capacitance: 1500pF Tol. 10%. Rated Voltage: 6.3Vdc |  |  |  |  |  |  |  | Murata |  |  |  | GRM011R60J152KE01L | 0201 Murata |  | None |  |  | https://www.snapeda.com/parts/GRM011R60J152KE01L/Murata/view-part/?ref=snap
C38 | 1uF | GRM011R60J152KE01L_2_GRM011R60J152KE01L | GRM011R60J152KE01L_2_CAPC0201X13N | Check availability |  |  | In Stock | https://www.snapeda.com/parts/GRM011R60J152KE01L/Murata/view-part/?ref=eda |  | SMD Capacitor X5R(EIA) with Capacitance: 1500pF Tol. 10%. Rated Voltage: 6.3Vdc |  |  |  |  |  |  |  | Murata |  |  |  | GRM011R60J152KE01L | 0201 Murata |  | None |  |  | https://www.snapeda.com/parts/GRM011R60J152KE01L/Murata/view-part/?ref=snap
C39 | 10uF | NORDIC_NRF_3_CAPACITOR_0201_L | NORDIC_NRF_3_RESC0201_L | Generic chip capacitor
C42 | 0.1uF | GRM011R60J152KE01L_2_GRM011R60J152KE01L | GRM011R60J152KE01L_2_CAPC0201X13N | Check availability |  |  | In Stock | https://www.snapeda.com/parts/GRM011R60J152KE01L/Murata/view-part/?ref=eda |  | SMD Capacitor X5R(EIA) with Capacitance: 1500pF Tol. 10%. Rated Voltage: 6.3Vdc |  |  |  |  |  |  |  | Murata |  |  |  | GRM011R60J152KE01L | 0201 Murata |  | None |  |  | https://www.snapeda.com/parts/GRM011R60J152KE01L/Murata/view-part/?ref=snap
C43 | 4.7uF | NORDIC_NRF_3_CAPACITOR_0201_L | NORDIC_NRF_3_RESC0201_L | Generic chip capacitor
D2 | MBR0530 | ESP32_C6_LIBRARY_5_MBR0530 | ESP32_C6_LIBRARY_5_SOD3716X135N | ON SEMICONDUCTOR - MBR0530 - DIODE, SCHOTTKY, 0.5A, 30V, SOD-123 |  |  | In Stock | https://www.snapeda.com/parts/MBR0530/Onsemi/view-part/?ref=eda |  | Diode Schottky 30 V 500mA Surface Mount SOD-123 |  |  |  |  |  |  |  | ON Semiconductor |  |  |  | MBR0530 | SOD-123-2 ON Semiconductor |  | None |  | https://www.snapeda.com/api/url_track_click_mouser/?unipart_id=179458&manufacturer=ON Semiconductor&part_name=MBR0530&search_term=None | https://www.snapeda.com/parts/MBR0530/Onsemi/view-part/?ref=snap
D3 | USBLC6-2SC6Y | ESP32_C6_LIBRARY_3_USBLC6-2SC6Y | ESP32_C6_LIBRARY_3_SOT95P280X145-6N | Low Cap. ESD Protection Auto SOT-23-6 STMicroelectronics USBLC6-2SC6Y, Dual Uni-Directional TVS Diode Array, 6-Pin SOT-23 |  |  | In Stock | https://www.snapeda.com/parts/USBLC6-2SC6Y/STMicroelectronics/view-part/?ref=eda |  | 17V Clamp 5A (8/20µs) Ipp Tvs Diode Surface Mount SOT-23-6 |  |  |  |  |  |  |  | STMicroelectronics |  |  |  | USBLC6-2SC6Y | SOT-23-6 STMicroelectronics |  | None |  |  | https://www.snapeda.com/parts/USBLC6-2SC6Y/STMicroelectronics/view-part/?ref=snap
D4 | MBR0530 | ESP32_C6_LIBRARY_5_MBR0530 | ESP32_C6_LIBRARY_5_SOD3716X135N | ON SEMICONDUCTOR - MBR0530 - DIODE, SCHOTTKY, 0.5A, 30V, SOD-123 |  |  | In Stock | https://www.snapeda.com/parts/MBR0530/Onsemi/view-part/?ref=eda |  | Diode Schottky 30 V 500mA Surface Mount SOD-123 |  |  |  |  |  |  |  | ON Semiconductor |  |  |  | MBR0530 | SOD-123-2 ON Semiconductor |  | None |  | https://www.snapeda.com/api/url_track_click_mouser/?unipart_id=179458&manufacturer=ON Semiconductor&part_name=MBR0530&search_term=None | https://www.snapeda.com/parts/MBR0530/Onsemi/view-part/?ref=snap
D5 | MBR0530 | ESP32_C6_LIBRARY_5_MBR0530 | ESP32_C6_LIBRARY_5_SOD3716X135N | ON SEMICONDUCTOR - MBR0530 - DIODE, SCHOTTKY, 0.5A, 30V, SOD-123 |  |  | In Stock | https://www.snapeda.com/parts/MBR0530/Onsemi/view-part/?ref=eda |  | Diode Schottky 30 V 500mA Surface Mount SOD-123 |  |  |  |  |  |  |  | ON Semiconductor |  |  |  | MBR0530 | SOD-123-2 ON Semiconductor |  | None |  | https://www.snapeda.com/api/url_track_click_mouser/?unipart_id=179458&manufacturer=ON Semiconductor&part_name=MBR0530&search_term=None | https://www.snapeda.com/parts/MBR0530/Onsemi/view-part/?ref=snap
EDP_C1 | 10uF | NORDIC_NRF_3_CAPACITOR_0201_L | NORDIC_NRF_3_RESC0201_L | Generic chip capacitor
EDP_C2 | 10uF | NORDIC_NRF_3_CAPACITOR_0201_L | NORDIC_NRF_3_RESC0201_L | Generic chip capacitor
EDP_C5 | 0.1uF/50V | NORDIC_NRF_3_CAPACITOR_0201_L | NORDIC_NRF_3_RESC0201_L | Generic chip capacitor
EDP_C6 | 1uF/50V | NORDIC_NRF_3_CAPACITOR_0201_L | NORDIC_NRF_3_RESC0201_L | Generic chip capacitor
EDP_C7 | 1uF/50V | NORDIC_NRF_3_CAPACITOR_0201_L | NORDIC_NRF_3_RESC0201_L | Generic chip capacitor
EDP_C8 | 1uF/50V | NORDIC_NRF_3_CAPACITOR_0201_L | NORDIC_NRF_3_RESC0201_L | Generic chip capacitor
EDP_C9 | 1uF/50V | NORDIC_NRF_3_CAPACITOR_0201_L | NORDIC_NRF_3_RESC0201_L | Generic chip capacitor
EDP_C10 | 1uF/50V | NORDIC_NRF_3_CAPACITOR_0201_L | NORDIC_NRF_3_RESC0201_L | Generic chip capacitor
EDP_C11 | 1uF/50V | NORDIC_NRF_3_CAPACITOR_0201_L | NORDIC_NRF_3_RESC0201_L | Generic chip capacitor
EDP_C12 | 1uF/50V | NORDIC_NRF_3_CAPACITOR_0201_L | NORDIC_NRF_3_RESC0201_L | Generic chip capacitor
IC1 | BQ25180YBGR | BQ25180YBGR_BQ25180YBGR | BQ25180YBGR_BGA8C40P2X4_100X155X50 | Charger IC Lithium Ion/Polymer, Lithium Iron Phosphate 8-DSBGA (1.6x1.1) | BQ25180YBGR | https://www.arrow.com/en/products/bq25180ybgr/texas-instruments?utm_currency=USD&region=nac |  |  |  | Charger IC Lithium Ion/Polymer, Lithium Iron Phosphate 8-DSBGA (1.6x1.1) |  |  |  | 0.5mm |  | Texas Instruments | BQ25180YBGR |  |  | 595-BQ25180YBGR | https://www.mouser.co.uk/ProductDetail/Texas-Instruments/BQ25180YBGR?qs=doiCPypUmgEWjAK%252BJAX6Tw%3D%3D
IC2 | DRV2605YZFR | DRV2605YZFR_DRV2605YZFR | DRV2605YZFR_BGA9C50P3X3_144X144X62 | Haptic Driver for ERM/LRA with Built-In Library and Smart Loop Architecture | DRV2605YZFR | https://www.arrow.com/en/products/drv2605yzfr/texas-instruments?region=nac |  |  |  | Haptic Driver for ERM/LRA with Built-In Library and Smart Loop Architecture |  |  |  | 0.625mm |  | Texas Instruments | DRV2605YZFR
IC3 | BMA421 | BMA423_BMA423 | BMA423_BMA423 | Accelerometers Triaxial low-g 12bit Acceleration Sensor | BMA423 | https://www.arrow.com/en/products/bma423/bosch |  |  |  | Accelerometers Triaxial low-g 12bit Acceleration Sensor |  |  |  | 1mm |  | BOSCH | BMA423 |  |  | 262-BMA423 | https://www.mouser.co.uk/ProductDetail/Bosch-Sensortec/BMA423?qs=HXFqYaX1Q2xC%252BSgeGoX3mg%3D%3D
IC9 | RT6160AWSC | RT6160AWSC_RT6160AWSC | RT6160AWSC_BGA15C40P3X5_140X230X60 | Buck-Boost Regulator Positive Output Step-Up/Step-Down I2C DC-DC Controller IC 15-WL-CSP (BSC) (1.4x2.3) |  |  |  |  |  | Buck-Boost Regulator Positive Output Step-Up/Step-Down I2C DC-DC Controller IC 15-WL-CSP (BSC) (1.4x2.3) |  |  |  | 0.6mm |  | RICHTEK | RT6160AWSC |  |  | 835-RT6160AWSC | https://www.mouser.co.uk/ProductDetail/Richtek/RT6160AWSC?qs=amGC7iS6iy%2FLd9PSoixZXQ%3D%3D
J1 | TC2030-IDC_TC2030-IDC | TC2030-IDC_TC2030-IDC | TC2030-IDC_TC2030IDC | CABLE ADAPTER 6 POS |  |  |  |  |  | CABLE ADAPTER 6 POS |  |  |  | 19mm |  | Tag Connect | TC2030-IDC
J2 | 503480-2400_503480-2400 | 503480-2400_503480-2400 | 503480-2400_5034802400 | FFC & FPC Connectors 0.5mm FPC RA SMT Dual Contact 24Ckt |  |  |  |  |  | FFC & FPC Connectors 0.5mm FPC RA SMT Dual Contact 24Ckt |  |  |  | 1.87mm |  | Molex | 503480-2400 |  |  | 538-503480-2400 | https://www.mouser.co.uk/ProductDetail/Molex/503480-2400?qs=OAhjpuo3Vu7efIoxFh9AOw%3D%3D
J4 | KH-TYPE-C-16P | KH-TYPE-C-16P_KH-TYPE-C-16P | KH-TYPE-C-16P_KINGHELM_KH-TYPE-C-16P | Check availability |  |  | Not in stock | https://www.snapeda.com/parts/KH-TYPE-C-16P/Kinghelm/view-part/?ref=eda |  |  |  |  |  |  |  |  |  | kinghelm |  |  |  | KH-TYPE-C-16P | None |  | None |  |  | https://www.snapeda.com/parts/KH-TYPE-C-16P/Kinghelm/view-part/?ref=snap
L1 | 3.9nH | NORDIC_NRF_2_INDUCTOR_0402_L | NORDIC_NRF_2_RESC0402_L | Generic chip inductor
L2 | 10uH | NORDIC_NRF_2_INDUCTOR_0402_L | NORDIC_NRF_2_RESC0402_L | Generic chip inductor
L3\ | 15nH | NORDIC_NRF_2_INDUCTOR_0402_L | NORDIC_NRF_2_RESC0402_L | Generic chip inductor
L5 | 68uH | ESP32_C6_LIBRARY_2_744043680IND_4828-WE-TPC_WRE | ESP32_C6_LIBRARY_2_IND_4828-WE-TPC_WRE |  |  |  |  |  | Copyright (C) 2024 Ultra Librarian. All rights reserved. |  |  |  |  |  |  |  | 744043680 |  | Wurth Electronics
L7 | FTC252012SR47MBCA | MLP2016SR47MT0S1_FTC252012SR47MBCA | MLP2016SR47MT0S1_INDC2016X100N | SMD / SMT Inductors (Coils), L=0.47?H, L x W x T : |  |  |  |  |  | SMD / SMT Inductors (Coils), L=0.47?H, L x W x T : |  |  |  | 1mm | https://jlcpcb.com/partdetail/6763488-FTC252012SR47MBCA/C5832368 | TDK | FTC252012SR47MBCA
Q1 | 20V/4.2A/52mO/1.4W | ESP32_C6_LIBRARY_4_ESP32_WROVER_SPARKFUN-DISCRETESEMI_MOSFET_PCH-DMG2305UX-7 | ESP32_C6_LIBRARY_4_ESP32_C6_LIBRARY_4_ESP32_C6_LIBRARY_4_ESP32_C6_LIBRARY_4_ESP32_WROVER_SPARKFUN-DISCRETESEMI_SOT23-3 | P-channel MOSFETs |  |  |  |  |  |  |  |  |  |  |  |  |  |  |  |  |  |  |  |  |  | TRAN-14388 |  |  |  | 20V/4.2A/52mO/1.4W
Q3 | SI1308EDL-T1-GE3 | ESP32_C6_LIBRARY_6_SI1308EDL-T1-GE3 | ESP32_C6_LIBRARY_6_SOT65P210X110-3N | MOSFET N-Ch 30V 1.5A TrenchFET SC70 Vishay Si1308EDL-T1-GE3 N-channel MOSFET Transistor, 1.5 A, 30 V, 3-Pin SC-70 |  |  | In Stock | https://www.snapeda.com/parts/SI1308EDL-T1-GE3/Vishay+Siliconix/view-part/?ref=eda |  | Si1308EDL-T1-GE3 N-channel MOSFET Transistor, 1.5 A, 30 V, 3-Pin SC-70 | Siliconix / Vishay SI1308EDL-T1-GE3 |  |  |  |  |  |  |  | Vishay Siliconix |  |  |  | SI1308EDL-T1-GE3 | SOT-323 Vishay Semiconductor |  | None |  | https://www.snapeda.com/api/url_track_click_mouser/?unipart_id=274603&manufacturer=Vishay Siliconix&part_name=SI1308EDL-T1-GE3&search_term=None | https://www.snapeda.com/parts/SI1308EDL-T1-GE3/Vishay+Siliconix/view-part/?ref=snap
R1 | 10K | CPF0201D7K68C1_CPF0201D7K68C1 | CPF0201D7K68C1_0201 | 7.68k 0201 Thin Film Surface Mount Fixed Resistor +/-0.5% 0.031W CPF0201D7K68C1
R1_EP_DR1 | 0.47 | CPF0201D7K68C1_CPF0201D7K68C1 | CPF0201D7K68C1_0201 | 7.68k 0201 Thin Film Surface Mount Fixed Resistor +/-0.5% 0.031W CPF0201D7K68C1
R1_USB | 5K1 | CPF0201D7K68C1_CPF0201D7K68C1 | CPF0201D7K68C1_0201 | 7.68k 0201 Thin Film Surface Mount Fixed Resistor +/-0.5% 0.031W CPF0201D7K68C1
R2 | 10K | CPF0201D7K68C1_CPF0201D7K68C1 | CPF0201D7K68C1_0201 | 7.68k 0201 Thin Film Surface Mount Fixed Resistor +/-0.5% 0.031W CPF0201D7K68C1
R2_EP_DR | 10K | CPF0201D7K68C1_CPF0201D7K68C1 | CPF0201D7K68C1_0201 | 7.68k 0201 Thin Film Surface Mount Fixed Resistor +/-0.5% 0.031W CPF0201D7K68C1
R2_USB | 5K1 | CPF0201D7K68C1_CPF0201D7K68C1 | CPF0201D7K68C1_0201 | 7.68k 0201 Thin Film Surface Mount Fixed Resistor +/-0.5% 0.031W CPF0201D7K68C1
R3 | 0 | CPF0201D7K68C1_CPF0201D7K68C1 | CPF0201D7K68C1_0201 | 7.68k 0201 Thin Film Surface Mount Fixed Resistor +/-0.5% 0.031W CPF0201D7K68C1
R5 | 10K | CPF0201D7K68C1_CPF0201D7K68C1 | CPF0201D7K68C1_0201 | 7.68k 0201 Thin Film Surface Mount Fixed Resistor +/-0.5% 0.031W CPF0201D7K68C1
R7 | 10K | CPF0201D7K68C1_CPF0201D7K68C1 | CPF0201D7K68C1_0201 | 7.68k 0201 Thin Film Surface Mount Fixed Resistor +/-0.5% 0.031W CPF0201D7K68C1
R8 | 10K | CPF0201D7K68C1_CPF0201D7K68C1 | CPF0201D7K68C1_0201 | 7.68k 0201 Thin Film Surface Mount Fixed Resistor +/-0.5% 0.031W CPF0201D7K68C1
R9 | 10K | CPF0201D7K68C1_CPF0201D7K68C1 | CPF0201D7K68C1_0201 | 7.68k 0201 Thin Film Surface Mount Fixed Resistor +/-0.5% 0.031W CPF0201D7K68C1
R17 | 3K3 | CPF0201D7K68C1_CPF0201D7K68C1 | CPF0201D7K68C1_0201 | 7.68k 0201 Thin Film Surface Mount Fixed Resistor +/-0.5% 0.031W CPF0201D7K68C1
R18 | 3K3 | CPF0201D7K68C1_CPF0201D7K68C1 | CPF0201D7K68C1_0201 | 7.68k 0201 Thin Film Surface Mount Fixed Resistor +/-0.5% 0.031W CPF0201D7K68C1
R_PWR_EPD | 10K | CPF0201D7K68C1_CPF0201D7K68C1 | CPF0201D7K68C1_0201 | 7.68k 0201 Thin Film Surface Mount Fixed Resistor +/-0.5% 0.031W CPF0201D7K68C1
R_TYPE_SEL | 2.2 | CPF0201D7K68C1_CPF0201D7K68C1 | CPF0201D7K68C1_0201 | 7.68k 0201 Thin Film Surface Mount Fixed Resistor +/-0.5% 0.031W CPF0201D7K68C1
SJ1 |  | ESP32_C6_LIBRARY_7_JUMPER_SJ | ESP32_C6_LIBRARY_7_JUMPER_SJ | SMD solder JUMPER |  |  |  |  |  |  |  |  |  |  |  |  |  |  |  |  |  |  |  | 3
SW_DN | 2025-10-22_07-23-44_LIBRARY_EVP-AKE31ASW_EVP-AKE31A_PAN | 2025-10-22_07-23-44_LIBRARY_EVP-AKE31ASW_EVP-AKE31A_PAN | 2025-10-22_07-23-44_LIBRARY_SW_EVP-AKE31A_PAN |  |  |  |  |  | Copyright (C) 2025 Ultra Librarian. All rights reserved. |  | P123437TR-ND | P123437CT-ND | P123437DKR-ND |  |  | Panasonic | EVP-AKE31A
SW_ENT | 2025-10-22_07-23-44_LIBRARY_EVP-AKE31ASW_EVP-AKE31A_PAN | 2025-10-22_07-23-44_LIBRARY_EVP-AKE31ASW_EVP-AKE31A_PAN | 2025-10-22_07-23-44_LIBRARY_SW_EVP-AKE31A_PAN |  |  |  |  |  | Copyright (C) 2025 Ultra Librarian. All rights reserved. |  | P123437TR-ND | P123437CT-ND | P123437DKR-ND |  |  | Panasonic | EVP-AKE31A
SW_UP | 2025-10-22_07-23-44_LIBRARY_EVP-AKE31ASW_EVP-AKE31A_PAN | 2025-10-22_07-23-44_LIBRARY_EVP-AKE31ASW_EVP-AKE31A_PAN | 2025-10-22_07-23-44_LIBRARY_SW_EVP-AKE31A_PAN |  |  |  |  |  | Copyright (C) 2025 Ultra Librarian. All rights reserved. |  | P123437TR-ND | P123437CT-ND | P123437DKR-ND |  |  | Panasonic | EVP-AKE31A
TP_3V3 | HECTOR_WATCH_1_TPTP20R | HECTOR_WATCH_1_TPTP20R | HECTOR_WATCH_1_TP20R | Test pad |  |  |  |  |  |  |  |  |  |  |  |  |  |  |  |  |  |  |  | 2
TP_3V3_2 | HECTOR_WATCH_1_TPTP20R | HECTOR_WATCH_1_TPTP20R | HECTOR_WATCH_1_TP20R | Test pad |  |  |  |  |  |  |  |  |  |  |  |  |  |  |  |  |  |  |  | 2
TP_BAT_GND | HECTOR_WATCH_1_TPTP20R | HECTOR_WATCH_1_TPTP20R | HECTOR_WATCH_1_TP20R | Test pad |  |  |  |  |  |  |  |  |  |  |  |  |  |  |  |  |  |  |  | 2
TP_GND | HECTOR_WATCH_1_TPTP20R | HECTOR_WATCH_1_TPTP20R | HECTOR_WATCH_1_TP20R | Test pad |  |  |  |  |  |  |  |  |  |  |  |  |  |  |  |  |  |  |  | 2
TP_ON | HECTOR_WATCH_1_TPTP20R | HECTOR_WATCH_1_TPTP20R | HECTOR_WATCH_1_TP20R | Test pad |  |  |  |  |  |  |  |  |  |  |  |  |  |  |  |  |  |  |  | 2
TP_OP | HECTOR_WATCH_1_TPTP20R | HECTOR_WATCH_1_TPTP20R | HECTOR_WATCH_1_TP20R | Test pad |  |  |  |  |  |  |  |  |  |  |  |  |  |  |  |  |  |  |  | 2
TP_RESET | HECTOR_WATCH_1_TPTP20R | HECTOR_WATCH_1_TPTP20R | HECTOR_WATCH_1_TP20R | Test pad |  |  |  |  |  |  |  |  |  |  |  |  |  |  |  |  |  |  |  | 2
TP_SCL | HECTOR_WATCH_1_TPTP20R | HECTOR_WATCH_1_TPTP20R | HECTOR_WATCH_1_TP20R | Test pad |  |  |  |  |  |  |  |  |  |  |  |  |  |  |  |  |  |  |  | 2
TP_SDA | HECTOR_WATCH_1_TPTP20R | HECTOR_WATCH_1_TPTP20R | HECTOR_WATCH_1_TP20R | Test pad |  |  |  |  |  |  |  |  |  |  |  |  |  |  |  |  |  |  |  | 2
TP_SWDCLK | HECTOR_WATCH_1_TPTP20R | HECTOR_WATCH_1_TPTP20R | HECTOR_WATCH_1_TP20R | Test pad |  |  |  |  |  |  |  |  |  |  |  |  |  |  |  |  |  |  |  | 2
TP_SWDIO | HECTOR_WATCH_1_TPTP20R | HECTOR_WATCH_1_TPTP20R | HECTOR_WATCH_1_TP20R | Test pad |  |  |  |  |  |  |  |  |  |  |  |  |  |  |  |  |  |  |  | 2
TP_SWO | HECTOR_WATCH_1_TPTP20R | HECTOR_WATCH_1_TPTP20R | HECTOR_WATCH_1_TP20R | Test pad |  |  |  |  |  |  |  |  |  |  |  |  |  |  |  |  |  |  |  | 2
TP_VBAT | HECTOR_WATCH_1_TPTP20R | HECTOR_WATCH_1_TPTP20R | HECTOR_WATCH_1_TP20R | Test pad |  |  |  |  |  |  |  |  |  |  |  |  |  |  |  |  |  |  |  | 2
TP_VREG | HECTOR_WATCH_1_TPTP20R | HECTOR_WATCH_1_TPTP20R | HECTOR_WATCH_1_TP20R | Test pad |  |  |  |  |  |  |  |  |  |  |  |  |  |  |  |  |  |  |  | 2
U1 | NRF52840_QF | NORDIC_NRF_4_NRF52840_QF | NORDIC_NRF_4_AQFN50P700X700X85_HS-74N | nRF52840
U2 | ESP32_C6_LIBRARY_MAX17048G+T10 | ESP32_C6_LIBRARY_MAX17048G+T10 | ESP32_C6_LIBRARY_SON50P200X200X80-9N | Check availability |  |  | In Stock | https://www.snapeda.com/parts/MAX17048G+T10/Analog+Devices/view-part/?ref=eda |  | 3µA 1-Cell/2-Cell Fuel Gauge with ModelGauge |  |  |  |  |  |  |  | Analog Devices |  |  |  | MAX17048G+T10 | TDFN-8 Maxim |  | None |  | https://www.snapeda.com/api/url_track_click_mouser/?unipart_id=329239&manufacturer=Analog Devices&part_name=MAX17048G+T10&search_term=None | https://www.snapeda.com/parts/MAX17048G+T10/Analog+Devices/view-part/?ref=snap
X1 | 32MHz | NORDIC_NRF_XTAL_32MHZ | NORDIC_NRF_BT-XTAL_2016_N
X2 | 32.726kHz | NORDIC_NRF_1_XTAL_32KHZ | NORDIC_NRF_1_XTAL_3215_N

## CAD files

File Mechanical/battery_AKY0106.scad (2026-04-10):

// =============================================================================
// InkTime Smartwatch - Battery 3D Model
// Component: Akyga AKY0106 (LP502030) LiPo Battery
// Dimensions from datasheet: 30 x 20 x 5 mm (L x W x H)
// Capacity: 250 mAh, Voltage: 3.7V
// =============================================================================
// Note: Battery will be soldered directly to test pads on the PCB
// (no JST connector used, to save space)
// =============================================================================

module battery_AKY0106() {
    // Main battery body dimensions (mm)
    battery_length = 30;
    battery_width  = 20;
    battery_height = 5;
    
    // Corner radius for the pouch cell
    corner_r = 1.5;
    
    color("Silver", 0.85)
    translate([0, 0, battery_height/2])
    minkowski() {
        cube([
            battery_length - 2*corner_r,
            battery_width - 2*corner_r,
            battery_height - 1
        ], center=true);
        cylinder(r=corner_r, h=0.5, $fn=32);
    }
    
    // Solder tab / wire leads (simplified - 2 pads)
    // Positive tab
    color("Red")
    translate([battery_length/2, battery_width/4, battery_height/2])
    cube([3, 2, 0.2], center=true);
    
    // Negative tab
    color("Black")
    translate([battery_length/2, -battery_width/4, battery_height/2])
    cube([3, 2, 0.2], center=true);
    
    // Label on battery
    color("DimGray")
    translate([0, 0, battery_height + 0.01])
    linear_extrude(0.1)
    text("LP502030", size=3, halign="center", valign="center", font="Liberation Sans:style=Bold");
}

// Render the battery
battery_AKY0106();

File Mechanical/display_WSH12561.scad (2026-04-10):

// =============================================================================
// InkTime Smartwatch - E-Paper Display 3D Model
// Component: Waveshare WSH-12561 (1.54" E-Paper Display)
// External Dimensions: 31.80 x 37.32 x 1.05 mm
// Display Active Area: 27.60 x 27.60 mm (200x200 pixels)
// Connector: 24-pin 0.5mm pitch FPC (rear-flip, 2.0H)
// =============================================================================

module display_WSH12561() {
    // External dimensions (mm)
    ext_width  = 31.80;
    ext_height = 37.32;
    ext_depth  = 1.05;
    
    // Active display area (mm)
    disp_width  = 27.60;
    disp_height = 27.60;
    
    // Display offset from edges (centered horizontally, offset vertically)
    disp_x_offset = (ext_width - disp_width) / 2;
    disp_y_offset = 5.0;  // offset from bottom edge
    
    // FPC cable dimensions
    fpc_width  = 13.0;   // 24 pins at 0.5mm pitch + margins
    fpc_length = 15.0;   // cable length extending from panel
    fpc_thick  = 0.3;    // FPC cable thickness
    
    // --- Main panel body ---
    color("DimGray", 0.9)
    cube([ext_width, ext_height, ext_depth]);
    
    // --- Active display area (white e-paper surface) ---
    color("White", 0.95)
    translate([disp_x_offset, disp_y_offset, ext_depth - 0.01])
    cube([disp_width, disp_height, 0.15]);
    
    // --- Thin bezel frame around active area ---
    color("Black", 0.8)
    translate([disp_x_offset - 0.3, disp_y_offset - 0.3, ext_depth + 0.13])
    difference() {
        cube([disp_width + 0.6, disp_height + 0.6, 0.05]);
        translate([0.3, 0.3, -0.1])
        cube([disp_width, disp_height, 0.3]);
    }
    
    // --- FPC cable ---
    color("Orange", 0.7)
    translate([(ext_width - fpc_width) / 2, ext_height, 0])
    cube([fpc_width, fpc_length, fpc_thick]);
    
    // --- FPC connector pads (gold-colored contact strips) ---
    color("Gold")
    translate([(ext_width - fpc_width) / 2 + 0.5, ext_height - 0.5, ext_depth - 0.3])
    for (i = [0:23]) {
        translate([i * 0.5, 0, 0])
        cube([0.3, 0.5, 0.3]);
    }
}

// Render the display
display_WSH12561();

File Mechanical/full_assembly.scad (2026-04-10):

// =============================================================================
// InkTime Smartwatch - Full Device Assembly (Exploded View)
// =============================================================================
// This file combines all components:
//   1. Enclosure / Case (approximation based on inktime_case.f3z shape)
//   2. E-Paper Display (WSH-12561)
//   3. PCB (custom board outline)
//   4. Battery (AKY0106 / LP502030)
//   5. Shaker Motor (FIT0774)
// =============================================================================
// To generate an exploded view, set explode = 1
// To generate assembled view, set explode = 0
// =============================================================================

// ===== CONFIGURATION =====
explode = 1;              // 0 = assembled, 1 = exploded view
explode_distance = 15;     // mm between layers in exploded view

// ===== IMPORTS =====
use <battery_AKY0106.scad>
use <display_WSH12561.scad>
use <shaker_FIT0774.scad>

// ===== PCB DIMENSIONS (approximate from board file) =====
// The PCB has a custom watch-shaped outline
pcb_width    = 36.0;    // approximate X dimension
pcb_height   = 40.0;    // approximate Y dimension
pcb_thick    = 1.6;     // standard FR-4 thickness

// ===== CASE DIMENSIONS (approximate from inktime_case.f3z) =====
case_width    = 38.0;
case_height   = 42.0;
case_depth    = 12.0;   // total case depth
case_wall     = 1.0;    // wall thickness
case_corner_r = 5.0;    // corner radius

// =============================================================================
// MODULE: Simplified PCB Outline
// =============================================================================
module pcb_board() {
    color("Green", 0.85)
    translate([0, 0, 0])
    linear_extrude(pcb_thick) {
        // Main body - rounded rectangle
        offset(r=3) offset(r=-3)
        union() {
            // Main rectangular area
            translate([-pcb_width/2, -pcb_height/2])
            square([pcb_width, pcb_height]);
        }
    }
    
    // USB-C connector cutout area (simplified block)
    color("Silver", 0.9)
    translate([-4.5, pcb_height/2 - 2, 0])
    cube([9, 7.5, 3.2]);
    
    // Buttons (3x side buttons on left edge) 
    for (i = [-1:1]) {
        color("DarkGray")
        translate([-pcb_width/2 - 1.5, i * 8, 0.3])
        cube([3, 3.5, 1.5]);
    }
    
    // BGA nRF52840 (center of board)
    color("DimGray")
    translate([-3.5, -3.5, pcb_thick])
    cube([7, 7, 0.85]);
    
    // Label on IC
    color("White")
    translate([0, 0, pcb_thick + 0.86])
    linear_extrude(0.05)
    text("nRF52840", size=1.5, halign="center", valign="center", font="Liberation Sans:style=Bold");
    
    // BMA423 IMU (bottom-left area)
    color("DimGray")
    translate([-14, -12, pcb_thick])
    cube([2, 2, 0.9]);
    
    // MAX17048 Fuel Gauge
    color("DimGray")
    translate([10, -8, pcb_thick])
    cube([2, 2, 0.8]);
    
    // BQ25180 Charger IC
    color("DimGray")
    translate([3, -8, pcb_thick])
    cube([1.6, 1.0, 0.5]);
    
    // RT6160A DC/DC
    color("DimGray")
    translate([-6, -7, pcb_thick])
    cube([2.3, 1.4, 0.6]);
    
    // DRV2605 Haptic Driver
    color("DimGray")
    translate([8, 5, pcb_thick])
    cube([1.44, 1.44, 0.62]);
    
    // E-Paper display connector (24-pin FPC)
    color("Tan")
    translate([6, 0, pcb_thick])
    cube([14, 3, 1.0]);
    
    // TC2030 debug header
    color("Gold")
    translate([8, 12, pcb_thick])
    for (r = [0:1]) {
        for (c = [0:2]) {
            translate([c * 1.27, r * 1.27, 0])
            cylinder(h=0.5, r=0.35, $fn=16);
        }
    }
    
    // Antenna area (chip antenna at edge)
    color("Gold")
    translate([pcb_width/2 - 5, 3, pcb_thick])
    cube([3.2, 1.6, 0.5]);
    
    // Crystals
    color("Silver")
    translate([-4, 4, pcb_thick])
    cube([2.0, 1.6, 0.6]);
    
    color("Silver")
    translate([2, 3, pcb_thick])
    cube([3.2, 1.5, 0.9]);
    
    // Various capacitors/resistors (0201 footprints scattered)
    color("Tan")
    for (i = [0:15]) {
        translate([
            -pcb_width/2 + 4 + (i % 4) * 7,
            -pcb_height/2 + 5 + floor(i / 4) * 8,
            pcb_thick
        ])
        cube([0.6, 0.3, 0.3]);
    }
    
    // Test pads (gold circles on various locations)
    color("Gold")
    for (pos = [
        [-12, 14], [12, 14], [-12, -14], [12, -14],
        [-15, 0], [15, 0], [-15, 8], [15, 8],
        [0, 16], [0, -16]
    ]) {
        translate([pos[0], pos[1], pcb_thick])
        cylinder(h=0.1, r=0.5, $fn=16);
    }
}

// =============================================================================
// MODULE: Case Bottom
// =============================================================================
module case_bottom() {
    color("DarkSlateGray", 0.8)
    difference() {
        // Outer shell
        translate([0, 0, 0])
        minkowski() {
            translate([-case_width/2 + case_corner_r, -case_height/2 + case_corner_r, 0])
            cube([
                case_width - 2*case_corner_r,
                case_height - 2*case_corner_r,
                case_depth/2 - 1
            ]);
            cylinder(r=case_corner_r, h=0.5, $fn=48);
        }
        
        // Inner cavity
        translate([0, 0, case_wall])
        minkowski() {
            translate([
                -case_width/2 + case_corner_r + case_wall,
                -case_height/2 + case_corner_r + case_wall,
                0
            ])
            cube([
                case_width - 2*(case_corner_r + case_wall),
                case_height - 2*(case_corner_r + case_wall),
                case_depth/2
            ]);
            cylinder(r=case_corner_r - case_wall/2, h=0.1, $fn=48);
        }
        
        // Button cutouts (3x on left side)
        for (i = [-1:1]) {
            translate([-case_width/2 - 1, i * 8 - 2, case_wall + 1])
            cube([case_wall + 2, 4, 2.5]);
        }
        
        // USB-C cutout
        translate([-5, case_height/2 - 1, case_wall + 1])
        cube([10, case_wall + 2, 4]);
    }
}

// =============================================================================
// MODULE: Case Top (glass/cover)
// =============================================================================
module case_top() {
    disp_window_w = 28.5;
    disp_window_h = 28.5;
    
    color("DarkSlateGray", 0.6)
    difference() {
        // Cover plate
        minkowski() {
            translate([
                -case_width/2 + case_corner_r,
                -case_height/2 + case_corner_r,
                0
            ])
            cube([
                case_width - 2*case_corner_r,
                case_height - 2*case_corner_r,
                1.5
            ]);
            cylinder(r=case_corner_r, h=0.2, $fn=48);
        }
        
        // Display window cutout
        translate([-disp_window_w/2, -disp_window_h/2 - 1, -0.5])
        cube([disp_window_w, disp_window_h, 3]);
    }
    
    // Transparent glass over display
    color("LightBlue", 0.2)
    translate([-disp_window_w/2, -disp_window_h/2 - 1, 0.2])
    cube([disp_window_w, disp_window_h, 0.8]);
}

// =============================================================================
// ASSEMBLY
// =============================================================================

// Layer offsets (from bottom)
z_case_bottom = 0;
z_battery     = case_wall + 0.5;
z_shaker      = case_wall + 0.5;
z_pcb         = z_battery + 5.5;
z_display     = z_pcb + pcb_thick + 0.5;
z_case_top    = z_display + 1.2;

// Explode multiplier
e = explode ? explode_distance : 0;

// --- Case Bottom ---
translate([0, 0, z_case_bottom - e * 2])
    case_bottom();

// --- Battery ---
translate([-15, -10, z_battery - e * 1])
    battery_AKY0106();

// --- Shaker Motor ---
translate([12, -12, z_shaker - e * 1])
    shaker_FIT0774();

// --- PCB ---
translate([0, 0, z_pcb])
    pcb_board();

// --- Display ---
translate([-31.80/2, -37.32/2 - 1, z_display + e * 1])
    display_WSH12561();

// --- Case Top ---
translate([0, 0, z_case_top + e * 2])
    case_top();

// --- Assembly labels (only in exploded view) ---
if (explode) {
    color("Black")
    translate([25, 0, z_case_top + e * 2 + 1])
    linear_extrude(0.1)
    text("Case Top", size=3, font="Liberation Sans");
    
    color("Black")
    translate([25, 0, z_display + e * 1 + 1])
    linear_extrude(0.1)
    text("E-Paper Display", size=3, font="Liberation Sans");
    
    color("Black")
    translate([25, 0, z_pcb + 1])
    linear_extrude(0.1)
    text("PCB", size=3, font="Liberation Sans");
    
    color("Black")
    translate([25, 0, z_battery - e * 1 + 1])
    linear_extrude(0.1)
    text("Battery + Shaker", size=3, font="Liberation Sans");
    
    color("Black")
    translate([25, 0, z_case_bottom - e * 2 + 1])
    linear_extrude(0.1)
    text("Case Bottom", size=3, font="Liberation Sans");
}

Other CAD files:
Mechanical/shaker_FIT0774.scad

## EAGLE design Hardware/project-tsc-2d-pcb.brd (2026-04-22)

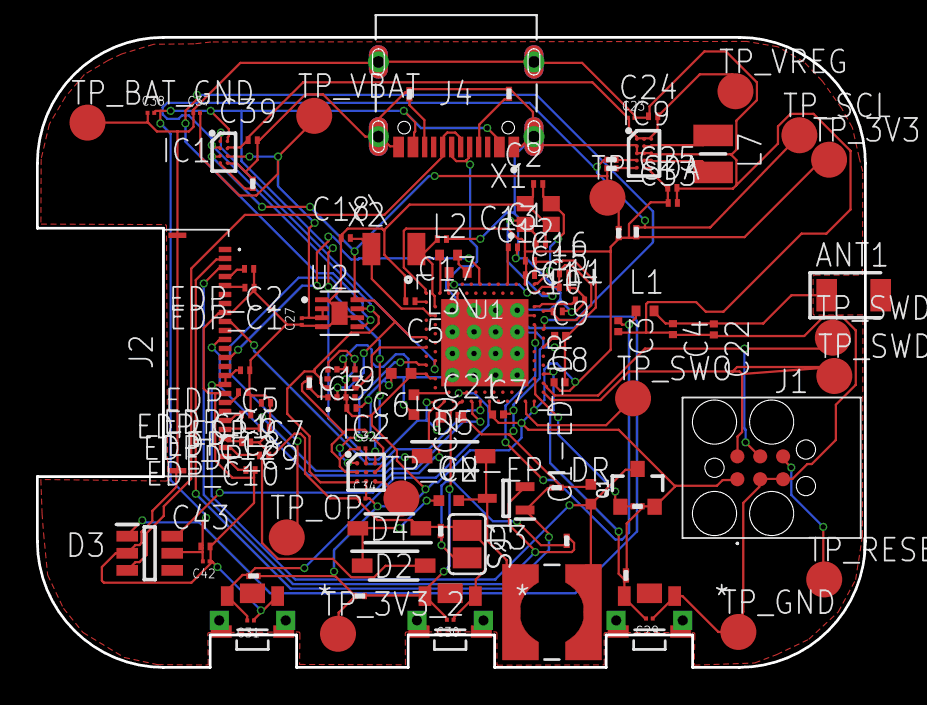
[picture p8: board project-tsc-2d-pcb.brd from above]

Board: 2 copper layers, 46.0 x 35.0 mm, 105 parts (0 on the bottom side), 70 nets.

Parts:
ANT1: 2450AT18B100E; 2450AT18B100E_ANTC3216X140N
C1, C2, C17, C18\: 12pF; NORDIC_NRF_3_RESC0201_L
C1-ED-DR: 10uF; NORDIC_NRF_3_RESC0402_N
C2-EP-DR, C6, C20, C21: 4.7uF; NORDIC_NRF_3_RESC0402_N
C3, C4: 1pF; NORDIC_NRF_3_RESC0201_N
C5, C12, C19: 100nF; NORDIC_NRF_3_RESC0201_L
C7, C8: 100nF; NORDIC_NRF_3_RESC0201_N
C9: 820pF; NORDIC_NRF_3_RESC0201_N
C10, C13: N.C.; NORDIC_NRF_3_RESC0201_L
C11: 100pF; NORDIC_NRF_3_RESC0201_L
C14, C43: 4.7uF; NORDIC_NRF_3_RESC0201_L
C15: 1.0uF; NORDIC_NRF_3_RESC0201_L
C16: 47nF; NORDIC_NRF_3_RESC0201_L
C22: N.C.; NORDIC_NRF_3_RESC0201_N
C23, C27, C34, C42: 0.1uF; GRM011R60J152KE01L_2_CAPC0201X13N
C24, C39: 10uF; NORDIC_NRF_3_RESC0201_L
C25, C33: 22uF; NORDIC_NRF_3_RESC0201_L
C29, C30, C31, C32, C37, C38: 1uF; GRM011R60J152KE01L_2_CAPC0201X13N
D2, D4, D5: MBR0530; ESP32_C6_LIBRARY_5_SOD3716X135N
D3: USBLC6-2SC6Y; ESP32_C6_LIBRARY_3_SOT95P280X145-6N
EDP_C1, EDP_C2: 10uF; NORDIC_NRF_3_RESC0201_L
EDP_C5: 0.1uF/50V; NORDIC_NRF_3_RESC0201_L
EDP_C6, EDP_C7, EDP_C8, EDP_C9, EDP_C10, EDP_C11, EDP_C12: 1uF/50V; NORDIC_NRF_3_RESC0201_L
IC1: BQ25180YBGR; BQ25180YBGR_BGA8C40P2X4_100X155X50
IC2: DRV2605YZFR; DRV2605YZFR_BGA9C50P3X3_144X144X62
IC3: BMA421; BMA423_BMA423
IC9: RT6160AWSC; RT6160AWSC_BGA15C40P3X5_140X230X60
J1: TC2030-IDC_TC2030-IDC; TC2030-IDC_TC2030IDC
J2: 503480-2400_503480-2400; 503480-2400_5034802400
J4: KH-TYPE-C-16P; KH-TYPE-C-16P_KINGHELM_KH-TYPE-C-16P
L1: 3.9nH; NORDIC_NRF_2_RESC0402_L
L2: 10uH; NORDIC_NRF_2_RESC0402_L
L3\: 15nH; NORDIC_NRF_2_RESC0402_L
L5: 68uH; ESP32_C6_LIBRARY_2_IND_4828-WE-TPC_WRE
L7: FTC252012SR47MBCA; MLP2016SR47MT0S1_INDC2016X100N
Q1: 20V/4.2A/52mΩ/1.4W; ESP32_C6_LIBRARY_4_ESP32_C6_LIBRARY_4_ESP32_C6_LIBRARY_4_ES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
Q3: SI1308EDL-T1-GE3; ESP32_C6_LIBRARY_6_SOT65P210X110-3N
R1, R2, R2_EP_DR, R5, R7, R8, R9: 10K; CPF0201D7K68C1_0201
R1_EP_DR1: 0.47; CPF0201D7K68C1_0201
R1_USB, R2_USB: 5K1; CPF0201D7K68C1_0201
R3: 0; CPF0201D7K68C1_0201
R17, R18: 3K3; CPF0201D7K68C1_0201
R_PWR_EPD: 10K; CPF0201D7K68C1_0201
R_TYPE_SEL: 2.2; CPF0201D7K68C1_0201
SJ1: ESP32_C6_LIBRARY_7_JUMPER_SJ
SW_DN: 2025-10-22_07-23-44_LIBRARY_EVP-AKE31ASW_EVP-AKE3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; 2025-10-22_07-23-44_LIBRARY_SW_EVP-AKE31A_PAN
SW_ENT: 2025-10-22_07-23-44_LIBRARY_EVP-AKE31ASW_EVP-AKE3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; 2025-10-22_07-23-44_LIBRARY_SW_EVP-AKE31A_PAN
SW_UP: 2025-10-22_07-23-44_LIBRARY_EVP-AKE31ASW_EVP-AKE3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; 2025-10-22_07-23-44_LIBRARY_SW_EVP-AKE31A_PAN
TP_3V3, TP_3V3_2: HECTOR_WATCH_1_TPTP20R; HECTOR_WATCH_1_TP20R
TP_BAT_GND: HECTOR_WATCH_1_TPTP20R; HECTOR_WATCH_1_TP20R
TP_GND: HECTOR_WATCH_1_TPTP20R; HECTOR_WATCH_1_TP20R
TP_ON: HECTOR_WATCH_1_TPTP20R; HECTOR_WATCH_1_TP20R
TP_OP: HECTOR_WATCH_1_TPTP20R; HECTOR_WATCH_1_TP20R
TP_RESET: HECTOR_WATCH_1_TPTP20R; HECTOR_WATCH_1_TP20R
TP_SCL: HECTOR_WATCH_1_TPTP20R; HECTOR_WATCH_1_TP20R
TP_SDA: HECTOR_WATCH_1_TPTP20R; HECTOR_WATCH_1_TP20R
TP_SWDCLK: HECTOR_WATCH_1_TPTP20R; HECTOR_WATCH_1_TP20R
TP_SWDIO: HECTOR_WATCH_1_TPTP20R; HECTOR_WATCH_1_TP20R
TP_SWO: HECTOR_WATCH_1_TPTP20R; HECTOR_WATCH_1_TP20R
TP_VBAT: HECTOR_WATCH_1_TPTP20R; HECTOR_WATCH_1_TP20R
TP_VREG: HECTOR_WATCH_1_TPTP20R; HECTOR_WATCH_1_TP20R
U1: NRF52840_QF; NORDIC_NRF_4_AQFN50P700X700X85_HS-74N
U2: ESP32_C6_LIBRARY_MAX17048G+T10; ESP32_C6_LIBRARY_SON50P200X200X80-9N
X1: 32MHz; NORDIC_NRF_BT-XTAL_2016_N
X2: 32.726kHz; NORDIC_NRF_1_XTAL_3215_N

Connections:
3V1: C5.1, U1.P$C1
3V3: C6.1, C7.1, C8.1, C12.1, C14.1, C19.1, C25.1, C33.1, C34.2, IC2.C2, IC3.3, IC3.7, IC3.10, IC9.E2, IC9.E3, J1.1, Q1.2, R5.1, R7.1, R8.1, R17.2, R18.2, R_PWR_EPD.1, TP_3V3.TP, TP_3V3_2.TP, U1.P$A22, U1.P$AD14, U1.P$AD23, U1.P$B1, U1.P$W1, U1.P$Y2
ALERT: U1.P$J24, U2.5
D+: D3.4, U1.P$AD6
D-: D3.6, U1.P$AD4
DN: D3.1, J4.A7, J4.B7
DP: D3.3, J4.A6, J4.B6
EPD_3V3: C1-ED-DR.1, EDP_C5.2, J2.15, J2.16, L5.2, Q1.3
EPD_BUSY: J2.9, U1.P$AD12
EPD_CS: J2.12, U1.P$K2
EPD_DC: J2.11, U1.P$AD10
EPD_RST: J2.10, U1.P$AC11
ESP_3V1: EDP_C6.2, J2.18
ESP_3V2: EDP_C7.2, J2.19
ESP_3V4: EDP_C8.2, J2.20
ESP_3V6: EDP_C10.2, J2.22
GDR: J2.2, Q3.1, R2_EP_DR.1
GND: C1.2, C1-ED-DR.2, C2.1, C3.2, C4.2, C5.2, C6.2, C7.2, C8.2, C9.2, C10.2, C11.2, C12.2, C13.2, C14.2, C15.2, C16.2, C17.1, C18\.1, C19.2, C20.2, C21.2, C22.2, C23.2, C24.1, C25.2, C27.1, C29.1, C30.1, C31.1, C32.1, C33.2, C34.1, C37.1, C38.1, C39.2, C42.1, C43.2, D3.2, D4.1, EDP_C1.1, EDP_C2.1, EDP_C5.1, EDP_C6.1, EDP_C7.1, EDP_C8.1, EDP_C9.1, EDP_C10.1, EDP_C11.2, EDP_C12.2, IC1.D2, IC2.B1, IC2.B3, IC3.8, IC3.9, IC9.B1, IC9.C1, IC9.C2, IC9.C3, J1.3, J1.5, J2.8, J2.17, J2.MP1, J2.MP2, J4.A1_B12, J4.A12_B1, J4.SH1, J4.SH2, J4.SH3, J4.SH4, R1_USB.1, R2_EP_DR.2, R2_USB.2, R3.1, R9.1, R_TYPE_SEL.2, SJ1.1, SW_DN.1, SW_ENT.1, SW_UP.1, TP_BAT_GND.TP, TP_GND.TP, U1.P$74, U1.P$75, U1.P$76, U1.P$77, U1.P$78, U1.P$79, U1.P$80, U1.P$81, U1.P$82, U1.P$83, U1.P$84, U1.P$85, U1.P$86, U1.P$87, U1.P$88, U1.P$89, U1.P$90, U1.P$B7, U1.P$F23, U2.1, U2.4, U2.6, U2.9, X1.2, X1.4
GND1: C17.2, U1.P$D2, X2.2
GND2: C18\.2, U1.P$F2, X2.1
GND3: C2.2, U1.P$A23, X1.3
HAPTIC_EN: IC2.A1, U1.P$U1
IMU_INT1: IC3.5, U1.P$N1
IMU_INT2: IC3.6, U1.P$P2
LX1: IC9.B2, IC9.B3, L7.1
LX2: IC9.D2, IC9.D3, L7.2
MOSI: J2.14, U1.P$B13
unnamed: L2.1, U1.P$B3
unnamed: L2.2, L3\.1
unnamed: C10.1, C15.1, C16.1, L3\.2, U1.P$B5, U1.P$E24
unnamed: R1_EP_DR1.2, R_TYPE_SEL.1, SJ1.2
unnamed: IC1.D1, R9.2
unnamed: C2-EP-DR.2, D5.2, L5.1, Q3.3
unnamed: C2-EP-DR.1, D2.1, D4.2
unnamed: J4.A5, R1_USB.2
unnamed: J4.B5, R2_USB.1
unnamed: EDP_C2.2, J2.4
unnamed: EDP_C1.2, J2.5
unnamed: C32.2, IC2.A2
unnamed: C13.1, U1.P$A18
unnamed: C11.1, U1.P$D23
unnamed: C1.1, U1.P$B24, X1.1
unnamed: IC9.D1, R1.2
unnamed: IC9.E1, R2.2
unnamed: EDP_C12.1, J2.24
unnamed: IC3.1, R3.2
unnamed: C20.1, U1.P$AC5
unnamed: C9.1, U1.P$N24
unnamed: ANT1.1, C4.1, C22.1, L1.2
unnamed: C3.1, L1.1, U1.P$H23
OUT+: IC2.A3, TP_OP.TP
OUT-: IC2.C3, TP_ON.TP
P0.13: C30.2, R5.2, SW_UP.2, U1.P$AD8
P0.14: C31.2, R8.2, SW_ENT.2, U1.P$AC9
P1.01: Q1.1, R_PWR_EPD.2, U1.P$Y23
P1.02: C29.2, R7.2, SW_DN.2, U1.P$W24
PMIC_INT: IC1.A1, U1.P$T2
PREVGH: D5.1, EDP_C9.2, J2.21
PREVGL: D2.2, EDP_C11.1, J2.23
RESE: J2.3, Q3.2, R1_EP_DR1.1
RESET: J1.6, TP_RESET.TP, U1.P$AC13
SCK: J2.13, U1.P$A12
SCL: IC1.B1, IC2.C1, IC3.12, R1.1, R17.1, TP_SCL.TP, U1.P$M2, U2.7
SDA: IC1.C1, IC2.B2, IC3.2, R2.1, R18.1, TP_SDA.TP, U1.P$L1, U2.8
SWDCLK: J1.4, TP_SWDCLK.TP, U1.P$AA24
SWDIO: J1.2, TP_SWDIO.TP, U1.P$AC24
SWO: TP_SWO.TP, U1.P$AD22
VBAT: C27.2, C37.2, IC1.C2, TP_VBAT.TP, U2.2, U2.3
VBUS: C21.1, C38.2, C42.2, C43.1, D3.5, IC1.A2, J4.A4_B9, J4.A9_B4, U1.P$AD2
VREG: C23.1, C24.2, C39.1, IC1.B2, IC9.A1, IC9.A2, IC9.A3, TP_VREG.TP

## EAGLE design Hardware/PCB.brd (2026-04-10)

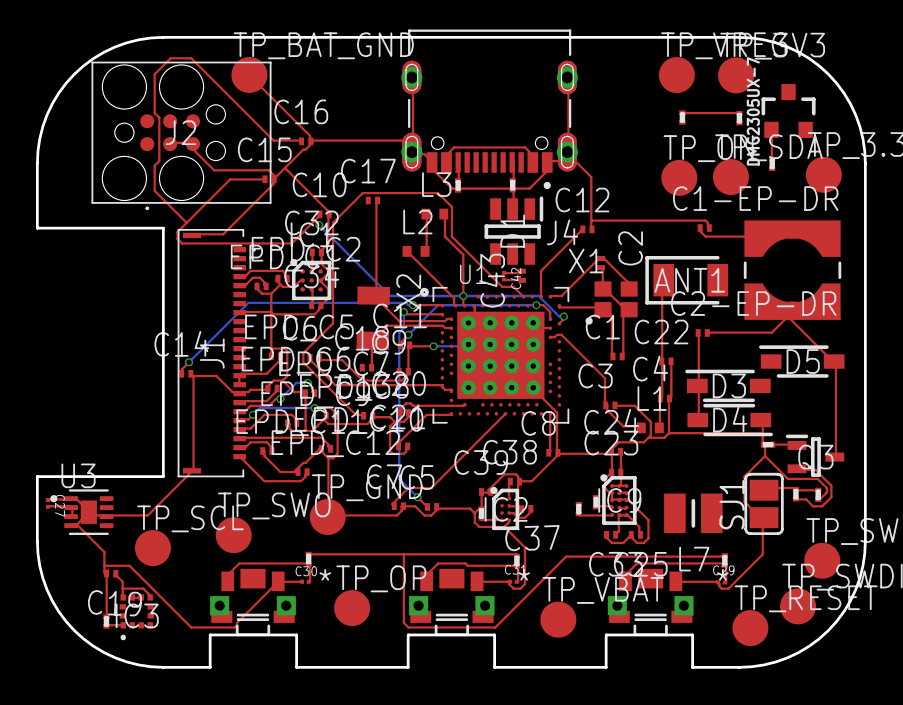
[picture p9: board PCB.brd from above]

Board: 2 copper layers, 46.0 x 35.0 mm, 105 parts (0 on the bottom side), 63 nets.

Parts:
ANT1: 2450AT18B100E_2450AT18B100E; 2450AT18B100E_ANTC3216X140N
C1, C2, C17, C18: 12pF; NORDIC_NRF_3_RESC0201_L
C1-EP-DR: 10µF; NORDIC_NRF_3_RESC0201_L
C2-EP-DR: 4.7µF/25V; NORDIC_NRF_3_RESC0201_L
C3, C4: 1pF; NORDIC_NRF_3_RESC0201_L
C5, C7, C8, C12, C19: 100nF; NORDIC_NRF_3_RESC0201_L
C6, C14, C20, C21: 4.7µF; NORDIC_NRF_3_RESC0201_L
C9: 820pF; NORDIC_NRF_3_RESC0201_L
C10, C13, C15, C22: N.C.; NORDIC_NRF_3_RESC0201_L
C11: 100pF; NORDIC_NRF_3_RESC0201_L
C16: 27nF; NORDIC_NRF_3_RESC0201_L
C23: 0.1uF; NORDIC_NRF_3_RESC0201_L
C24: 10uF; NORDIC_NRF_3_RESC0201_L
C25, C33: 22uF; NORDIC_NRF_3_RESC0201_L
C27, C29, C30, C31, C42: GRM011R60J152KE01L_2_GRM011R60J152KE01L; GRM011R60J152KE01L_2_CAPC0201X13N
C32: 1µF; NORDIC_NRF_3_RESC0201_L
C34: 0.1µF; NORDIC_NRF_3_RESC0201_L
C37, C38, C39: NORDIC_NRF_3_RESC0201_L
C43: 4.7uF; NORDIC_NRF_3_RESC0201_L
D1: ESP32_C6_LIBRARY_3_USBLC6-2SC6Y; ESP32_C6_LIBRARY_3_SOT95P280X145-6N
D3, D4, D5: ESP32_C6_LIBRARY_5_MBR0530; ESP32_C6_LIBRARY_5_SOD3716X135N
DMG2305UX-7: 20V/4.2A/52mΩ/1.4W; ESP32_C6_LIBRARY_4_ESP32_C6_LIBRARY_4_ESP32_C6_LIBRARY_4_ES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
EPD_C1, EPD_C2: 1uF/50V; NORDIC_NRF_3_RESC0201_L
EPD_C5, EPD_C6, EPD_C7, EPD_C8, EPD_C9, EPD_C10, EPD_C11, EPD_C12: 0.1uF/50V; NORDIC_NRF_3_RESC0201_L
IC1: DRV2605YZFR_DRV2605YZFR; DRV2605YZFR_BGA9C50P3X3_144X144X62
IC2: BQ25180YBGR_BQ25180YBGR; BQ25180YBGR_BGA8C40P2X4_100X155X50
IC3: BMA423_BMA423
IC9: RT6160AWSC_RT6160AWSC; RT6160AWSC_BGA15C40P3X5_140X230X60
J1: 503480-2400_503480-2400; 503480-2400_5034802400
J2: TC2030-IDC_TC2030-IDC; TC2030-IDC_TC2030IDC
J4: KH-TYPE-C-16P_KH-TYPE-C-16P; KH-TYPE-C-16P_KINGHELM_KH-TYPE-C-16P
L1: 3.9nH; NORDIC_NRF_2_RESC0402_L
L2: 10µH; NORDIC_NRF_2_RESC0402_L
L3: 15nH; NORDIC_NRF_2_RESC0402_L
L5: 68uH; ESP32_C6_LIBRARY_2_IND_4828-WE-TPC_WRE
L7: MLP2016SR47MT0S1_FTC252012SR47MBCA; MLP2016SR47MT0S1_INDC2016X100N
Q3: ESP32_C6_LIBRARY_6_SI1308EDL-T1-GE3; ESP32_C6_LIBRARY_6_SOT65P210X110-3N
R1_EP_DR, R1_USB, R2, R2_EP_DR, R2_USB, R3, R4, R5, R7, R8, R9, R17, R18: ERA-1AEB3401C_CPF0201D7K68C1; ERA-1AEB3401C_0201
R_PWR_EPD: ERA-1AEB3401C_CPF0201D7K68C1; ERA-1AEB3401C_0201
R_TYPE_SEL: ERA-1AEB3401C_CPF0201D7K68C1; ERA-1AEB3401C_0201
SJ1: ESP32_C6_LIBRARY_7_JUMPER_SJ
SW_DN: 2025-10-22_07-23-44_LIBRARY_EVP-AKE31ASW_EVP-AKE3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; 2025-10-22_07-23-44_LIBRARY_SW_EVP-AKE31A_PAN
SW_ENT: 2025-10-22_07-23-44_LIBRARY_EVP-AKE31ASW_EVP-AKE3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; 2025-10-22_07-23-44_LIBRARY_SW_EVP-AKE31A_PAN
SW_UP: 2025-10-22_07-23-44_LIBRARY_EVP-AKE31ASW_EVP-AKE3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; 2025-10-22_07-23-44_LIBRARY_SW_EVP-AKE31A_PAN
TP_3.3V, TP_3V3: HECTOR_WATCH_1_TPTP20R; HECTOR_WATCH_1_TP20R
TP_BAT_GND: HECTOR_WATCH_1_TPTP20R; HECTOR_WATCH_1_TP20R
TP_GND: HECTOR_WATCH_1_TPTP20R; HECTOR_WATCH_1_TP20R
TP_ON: HECTOR_WATCH_1_TPTP20R; HECTOR_WATCH_1_TP20R
TP_OP: HECTOR_WATCH_1_TPTP20R; HECTOR_WATCH_1_TP20R
TP_RESET: HECTOR_WATCH_1_TPTP20R; HECTOR_WATCH_1_TP20R
TP_SCL: HECTOR_WATCH_1_TPTP20R; HECTOR_WATCH_1_TP20R
TP_SDA: HECTOR_WATCH_1_TPTP20R; HECTOR_WATCH_1_TP20R
TP_SWDCLK: HECTOR_WATCH_1_TPTP20R; HECTOR_WATCH_1_TP20R
TP_SWDIO: HECTOR_WATCH_1_TPTP20R; HECTOR_WATCH_1_TP20R
TP_SWO: HECTOR_WATCH_1_TPTP20R; HECTOR_WATCH_1_TP20R
TP_VBAT: HECTOR_WATCH_1_TPTP20R; HECTOR_WATCH_1_TP20R
TP_VREG: HECTOR_WATCH_1_TPTP20R; HECTOR_WATCH_1_TP20R
U1: NORDIC_NRF_4_NRF52840_QF; NORDIC_NRF_4_AQFN50P700X700X85_HS-74N
U3: ESP32_C6_LIBRARY_MAX17048G+T10; ESP32_C6_LIBRARY_SON50P200X200X80-9N
X1: NORDIC_NRF_BT-XTAL_2016_N
X2: 32.768kHz; NORDIC_NRF_1_XTAL_3215_N

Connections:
GND: C1-EP-DR.2, C3.2, C4.2, C5.2, C6.2, C7.2, C8.2, C9.2, C10.2, C11.2, C12.2, C13.2, C14.2, C15.2, C16.2, C19.2, C20.2, C21.2, C22.2, C23.1, C24.1, C25.2, C27.1, C29.1, C30.1, C31.1, C32.2, C33.2, C34.2, C37.2, C38.2, C39.1, C39.2, D1.2, D4.1, EPD_C1.1, EPD_C2.1, EPD_C5.1, EPD_C6.1, EPD_C7.1, EPD_C8.1, EPD_C9.1, EPD_C10.1, EPD_C11.1, EPD_C12.1, IC1.B1, IC1.B3, IC2.B2, IC2.D2, IC9.B1, IC9.C1, IC9.C2, IC9.C3, J1.8, J1.17, J1.MP1, J1.MP2, J2.3, J2.5, J4.A1_B12, J4.A12_B1, J4.SH1, J4.SH2, J4.SH3, J4.SH4, R1_USB.2, R2_EP_DR.1, R2_USB.2, R3.1, R9.1, R_TYPE_SEL.1, SJ1.1, SW_DN.1, SW_ENT.1, SW_UP.1, TP_BAT_GND.TP, TP_GND.TP, U1.P$74, U1.P$75, U1.P$76, U1.P$77, U1.P$78, U1.P$79, U1.P$80, U1.P$81, U1.P$82, U1.P$83, U1.P$84, U1.P$85, U1.P$86, U1.P$87, U1.P$88, U1.P$89, U1.P$90, U1.P$B7, U1.P$F23, U3.1, U3.4, U3.6, U3.9
GND1: R1_EP_DR.1, R_TYPE_SEL.2, SJ1.2
GND2: C29.2, R7.1, SW_DN.2
GND3: C31.2, R8.1, SW_ENT.2
GND4: C30.2, R5.1, SW_UP.2
unnamed: IC2.D1, R9.2
unnamed: C38.1, IC2.A2
unnamed: C37.1, IC2.C2
unnamed: C23.2, C24.2, IC9.A1, IC9.A2, IC9.A3
unnamed: IC9.B2, IC9.B3
unnamed: IC9.D1, R4.2
unnamed: R17.1, R18.1
unnamed: IC9.D2, IC9.D3
unnamed: C25.1, C33.1, IC9.E2, IC9.E3
unnamed: IC9.E1, R2.2
unnamed: C19.1, IC3.7, IC3.10
unnamed: IC3.8, IC3.9
unnamed: IC3.1, R3.2
unnamed: C7.1, U1.P$AD14
unnamed: C21.1, U1.P$AD2
unnamed: C8.1, U1.P$AD23
unnamed: C3.1, L1.1, U1.P$H23
unnamed: ANT1.1, C4.1, C22.1, L1.2
unnamed: C10.1, C15.1, C16.1, L3.2, U1.P$B5, U1.P$E24
unnamed: C11.1, U1.P$D23
unnamed: C1.1, U1.P$B24, X1.1
unnamed: C2.1, U1.P$A23, X1.3
unnamed: C1.2, C2.2, X1.2, X1.4
unnamed: C12.1, U1.P$A22
unnamed: C13.1, U1.P$A18
unnamed: L2.2, L3.1
unnamed: L2.1, U1.P$B3
unnamed: C20.1, U1.P$AC5
unnamed: C6.1, U1.P$W1, U1.P$Y2
unnamed: C14.1, U1.P$B1
unnamed: C5.1, U1.P$C1
unnamed: C17.2, U1.P$D2, X2.1
unnamed: C18.2, U1.P$F2, X2.2
unnamed: C1-EP-DR.1, L5.2
unnamed: C2-EP-DR.2, D5.2, L5.1, Q3.3
unnamed: C2-EP-DR.1, D3.1, D4.2
unnamed: Q3.1, R2_EP_DR.2
unnamed: Q3.2, R1_EP_DR.2
unnamed: DMG2305UX-7.1, R_PWR_EPD.1
unnamed: C32.1, IC1.A2
unnamed: C34.1, IC1.C2
unnamed: R5.2, R7.2, R8.2
unnamed: C27.2, U3.2, U3.3
unnamed: EPD_C12.2, J1.24
unnamed: EPD_C2.2, J1.4
unnamed: EPD_C1.2, J1.5
unnamed: EPD_C5.2, J1.15, J1.16
unnamed: EPD_C11.2, J1.23
unnamed: EPD_C10.2, J1.22
unnamed: EPD_C9.2, J1.21
unnamed: EPD_C8.2, J1.20
unnamed: EPD_C7.2, J1.19
unnamed: EPD_C6.2, J1.18
unnamed: J4.A4_B9, J4.A9_B4
unnamed: J4.B5, R2_USB.1
unnamed: J4.A5, R1_USB.1
unnamed: C42.2, C43.1
unnamed: C42.1, C43.2

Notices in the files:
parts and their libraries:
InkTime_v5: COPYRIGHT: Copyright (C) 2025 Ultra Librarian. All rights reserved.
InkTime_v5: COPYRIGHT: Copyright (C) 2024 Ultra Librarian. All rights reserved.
